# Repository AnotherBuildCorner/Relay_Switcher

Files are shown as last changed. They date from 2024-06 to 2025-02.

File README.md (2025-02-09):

# Relay_Switcher
DIY Relay bypass switcher for audio applications

Are you a Guitarist/Bassist?  Do you have a pedalboard that just keeps on getting more complicated?

Worried about losing the high end to the long capactive runs and buffers?

Or maybe you want the ability to control your Star-Trek level board from a small controller on your desk?

Or maybe you looked at the avaliable products, and practically fell out of your chair with the price tag?

Then look no further! In this project you'll find a modular capable, mono or stereo loop bypass switcher with wireless control capability.

## Notes:
V3 Jackless Is up and running in the same 6 back stacked form factor as V2. At this point I believe this represents the final version for this current system based on the WROOM32E. Why?
- After designing this board, I became aware of smaller form factor ESP32's such as the XIAO C6 platform, which is roughly the size of a US Quarter, and has enough GPIO pins to support at least 6 relays.
- These smaller implementations also appear to handle the mesh network past 4 nodes. In the past, while possible, implementing past 4 nodes required additional edits deep in the IDE that I was unable to implement at the time.
- With these smaller nodes, I may be able to use one C6 to control a 6 to 8 loop package box. Incorporated directly into the loop box. Meaning the only wires needed will be Power, and audio. No more RJ45 signal control wire.
- Further, with the practical limitiations of how many nodes are available lifted. The use of C6 nodes means the modularity is further improved to the point of having a control box behind the amp for example, in an effects loop configuration, and one or two on the main pedalboard.  Or even separate pedalboards for different uses.  Or different layers of a rack. The possibilites are endless.
- With a couple small onboard changes, power may even be supplied by the onboard USB connector. Which on it's face doesn't seem that helpful in a 9V power dominated space. However, commercial 5V to 9V power adapters are readily available, which means an entire system could be run from USB power, and by extension, the widely available USB power packs on the market. Why Boost the voltage, just to regulate back to 5V when the supply can be run on pure 5V?

V2 Jackless is up and running in a 6 bay stacked model. In the process a handful of lessons were picked up.
- One, for the jackless model a V3 utilizing probably 3 loops on a single panel with built in signal traces, and possibly breakaway functionality is likely. Attempting to wire the board interconnects resulted in a bit of a mess, one I'm not entirely happy with.
- Two, The original implementations use a completely separate power/control and signal path, not even the grounds are linked. This appears to be an error, and a future revision may include a solderable ground linking pad. In testing this linkage reduced the noise to virtually 0
- Three, the breakout board, while universal has a quirk. When used with the current V2 coms board, Power and ground on the 8 pins are not next to one another. Careful: This may fry some boards.
- Four, some of the pins used on the ESP-32 were linked to serial output, so when those pins are active, the serial monitor and control are disabled. 
## PCB's
### Main Driver Board
### V3
The V3 Design implements some of the noted design problems from V2. Development has continued exclusively with the 3.5mm pitch model. As these are the parts I have on hand. and increasing the terminal block size appears to have little practical benefit.

 Instead of utilizing individual loop boards, there are now a pair of boards linked by a ribbon cable. As a set, these combined boards can support either 6 mono/stereo loops, or 5 mono/stero loops and a mono input selector depending on relay configuration.

 Input Board
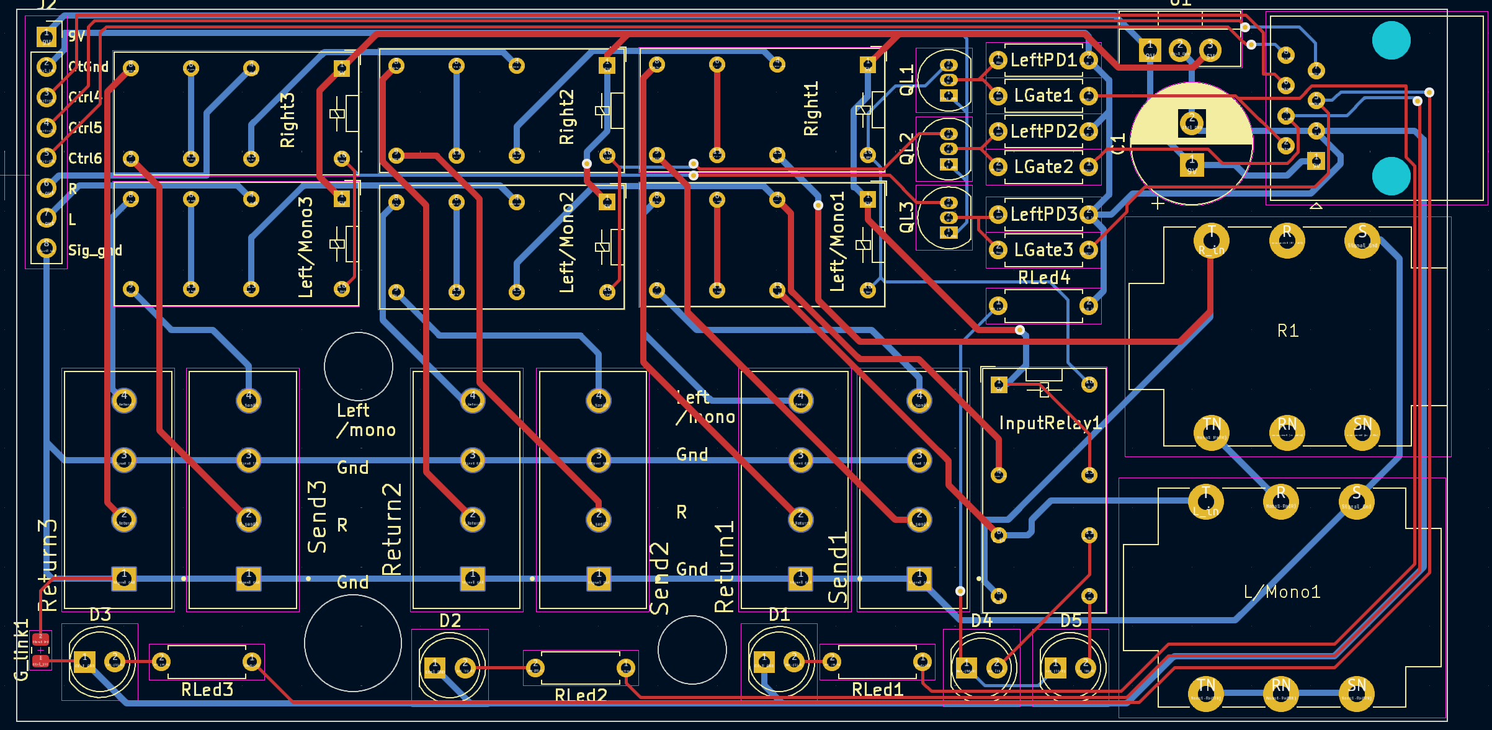
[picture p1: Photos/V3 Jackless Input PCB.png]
V3 jackless input PCB
 

 Output Board
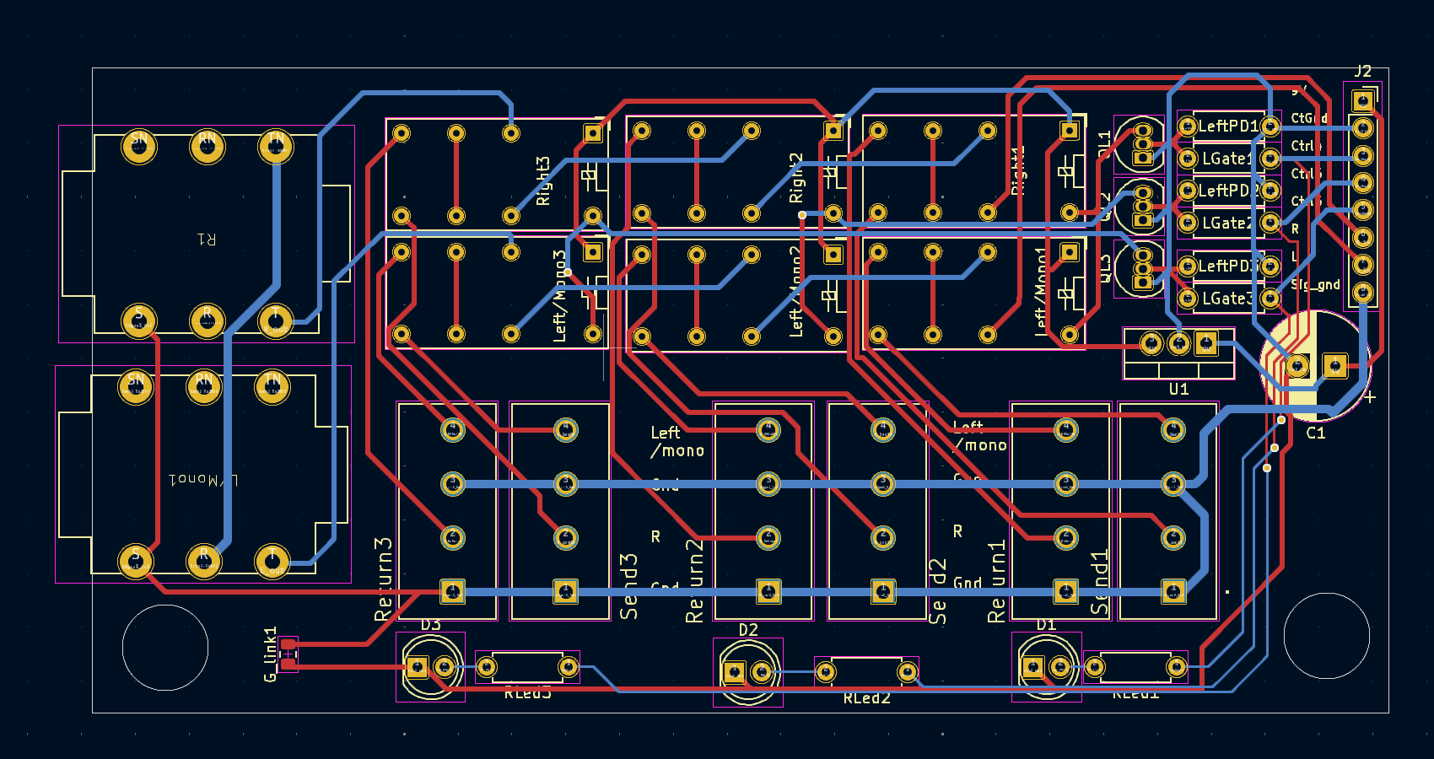
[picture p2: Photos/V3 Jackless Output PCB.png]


This change produces a couple of benefits. First is wiring is vastly improved. with the total wire soldering point count down from 7 per board ( L/R in, L/R out, Ground 9V, and Control signal.) Times 6 loop packages, for a total of 42 solder points. To 16 solder points total for the entire package. As well as being inline, ideal for a ribbon cable, as opposed to scattered across the board.

Additionally, the number of Voltage regulators is down from one per package, to one per PCB (with 3 loops on each). so a 66% reduction overall.

The mentioned power and signal ground linking has been added, provided by the G_link pads located on each PCB, in practice using booth may create a ground loop, so ideally soldering just one is reccomended.

Now the one loss from such a design (albeit minimal in practical usage) is the loops can no longer be order changed by moving around connectors inside the package (or perhaps in the future a complex multi relay network).  In practice this just means physically changing the order of the connected devices at the device instead, and is a minimal downside.

Both Boards Populated
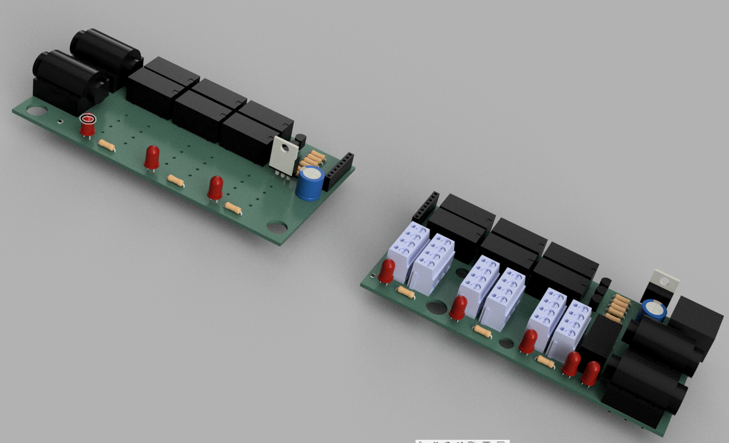
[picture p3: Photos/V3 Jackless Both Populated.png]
Populated


Complete Stacked model Assembly
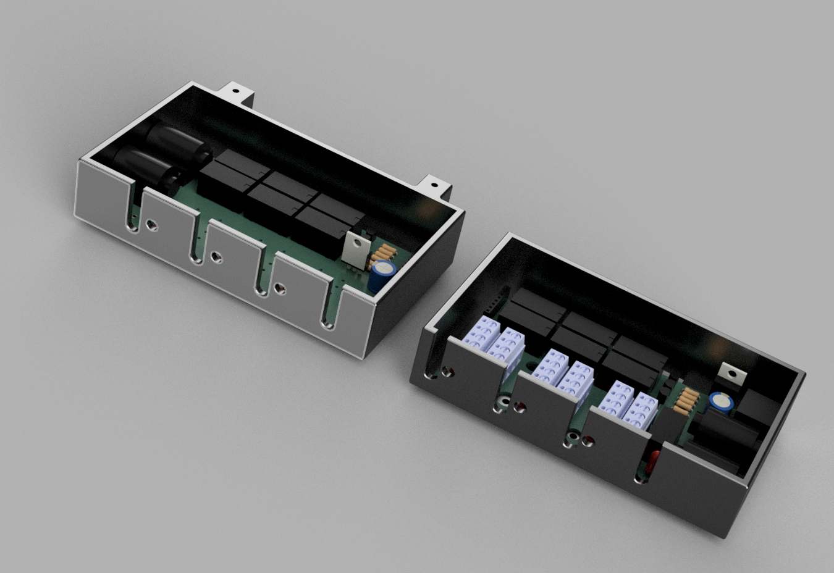
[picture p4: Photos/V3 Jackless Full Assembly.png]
Complete Assembly

### V2



V2 makes some significant improvements over the V1 design. And introduces a second design.
the changes are as follows
- Length of board reduced to 61mm Long
- Reduced count of 2n7000 MOSFET drivers from 3 to 1
- Tied status LED directly to the control output for a net -1 2n7000
- Tied the two relay coils together, controlled by single 2n7000

  Among the boards are now the standard stereo jack model, and a pair of new "jackless" models
  The jackless models utilize either a 4x3.5mm pitch or 4x5mm pitch screw terminal block on the IO. this reduces the cost per loop by up $10 in full implementation
  Additionally, it appears the space consumption overall will be significantly reduced with the new design
  




  The reduced board size should enable either the w/ jack or jackless versions to fit inside a standard 1032L Aluminium looper case
  In testing, the relay coils consume 30mA each, well under the 2n7000's maximum 200mA current.
  the new status LED position can also function as a pulldown for the inputs, reduces the 2n7000 count. And the originals had some current leakage which caused the led to be partially illuminated all the time

### V1


Pictured above is the main relay board. The core Arcitecture is one 5V coil DPDT Relay per signal channel. So for stereo configurations, two relays are required.
Each Relay is driven by a MOSFET 2n7000 switch circuit. As well as the status LED. All three MOSFET gates are tied to a common signal pin, and configured for 3.3V logic.

Each board is also equipped with a 74L05 5V regulator to drop the incoming 9V power, and provide supply for the relay switching.

Each board also has dual power connectors, as well as 3 pin 2.54mm spaced pins for the signal  this alows for easy connections between multiple boards in series.

Finally, the boards are set up to accept switched 1/4 inch stereo jacks. With the switches internally connected, so loops without connections pass signal in either active or inactive state.

(Add PCB wire photos here)

Of further note, was the consideration to keep audio, and control/ power wires as far away, and with minimal crossing as possible. This is to reduce crosstalk from the processor and power supplies into the audio path.

Future iterations will focus on compressing the PCB into a space suitable for a 16L Aluminium looper enclosure. Or possibly a design set up to directly connect to the mono/stereo signal wires, therby reducing the need for the 1/4 Barrel connectors, and reducing the required 1/4 Plugs by 1/2.  This also helps with space considerations.  Considering these plugs cost upwards of $4 each, cutting in half is most welcome, although this reduces how universal this device will be.

### Processor Board
### V2


Changes from V1 to V2 are a different footprint ESP32.  now the Wroom 32E is the standard, with 38 pins avaiable.
The individual pin headers have been replaced by 3x rj45 connectors. each is configured with 6 individual GPIO pins, as well as a 9V connection, and ground.
Additionally, a new breakout board for the rj45 on the receiver end has been created.


### V1


The microprocessor controlling the relays is an ESP32 Devkit C V3 Chosen for it's relative availability, low price, access to Arduino IDE code, and most importantly the dedicated ESP_NOW wireless communication protocol, which will be used to communicate between boards.
This is a relatively simple IO board for connecting to the GPIO of the processor board. The only extra element is another 74L05 voltage regulator connected to the 5V input of the dev board and the 4 pullup resistors slotted in on GPIO pins which only provide input (not suitable for the relay control, but there are already plenty of pins available for most applications).

One shortcoming, there may not be enough GPIO pins to handle the control switches, status LED's, screen, and rotary encoder(s). But this is all currently under development.

This version has a single easily remedied flaw. I had to create a footprint for the ESP32 used as they were what I had to hand, but appear to no longer be made. Well I flipped a ground and power connection, shorting 3.3V power to ground. For now it's just a matter of cutting the trace.

Future versions will probably switch to using a V4 devkit, or the newer devkits based on the S3 processor for more GPIO, and to retain more current availability. 

### IO Board
### V2


The new V2 board corrects an error in the input switching, resulting in one of the inputs being completely unusable.
Additionally, the board size has been significantly reduced in length. and the IO board direct pinouts have been moved directly under each jack.

### V1


This is very similar to the main relay boards.
The differences are the use of the single relay, the dual LED indicators, and the large electrolytic capacitor on the 9V rail.
The Capacitor is a filtering cap, as most of the 9V power supplies will be switched mode supplies, and noise prone.
The relay is no longer used to enable/disable a loop. but instead is used to switch between two possible inputs/outputs. With the other half of the relay dedicated to controlling the indicator LED's
lastly there are direct pinouts on the back of each 1/4 Barrel connector. Should switching features not be desired, these can be used to link the relay loops directly to an output without extra parts.

## Housings
### Control Housing 


### Relay housing V2 
JAckless model.


The latest relay switch is setup to accept 5 of the jackless relay boards, and one V2 IO board with the RJ45 connection board in front.  however this new model is half the height of V1, and is stackable. By splitting the units into modules of 5, this enables break points for things such as Volume pedals, and always on boosts between loop modules. Additional smaller size stackable modules will likely be produced in the future. No one single module can exceed more than 6 relay modules due to the RJ45 connection's configuration.

### Relay housing V1
(picure)
The current housing design uses horizontally stacked relay loops, with a total count of 10. Plus the input and output boards. The IO is located on the front for accesibility, with the loops located on the back.

### Control Housing
(picture
The current design is a single print, 6 switch control with provisions to add a 128X64 OLED.
At present this is in it's early stages, so no provisions to mount the control board, or a larger screen have been included. This will come around in V2  The footswitches are spaced to allow foot, or hand use currently. And the board can be purely powered from a 5V usb supply though the ESP32 board.

## Code
(Coming Soon...)

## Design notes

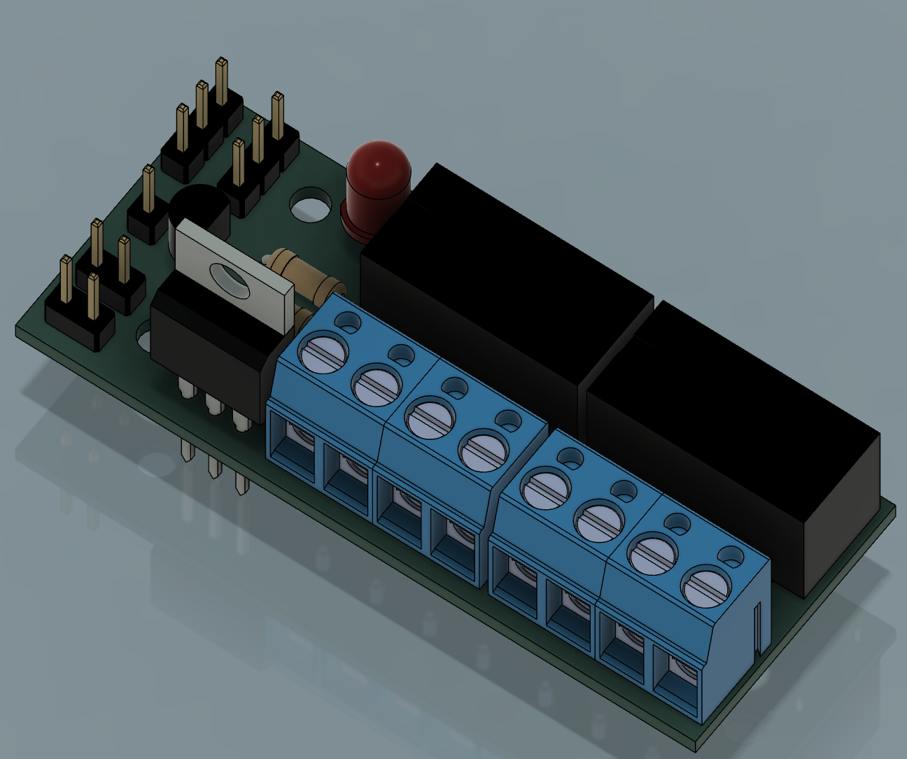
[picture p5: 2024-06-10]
Photos/Screenshot 2024-06-09 212600.png

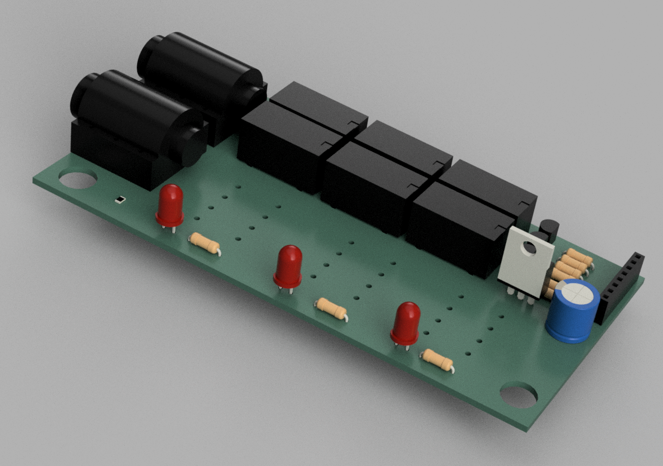
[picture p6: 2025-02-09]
Photos/V3 jackless Output only.png

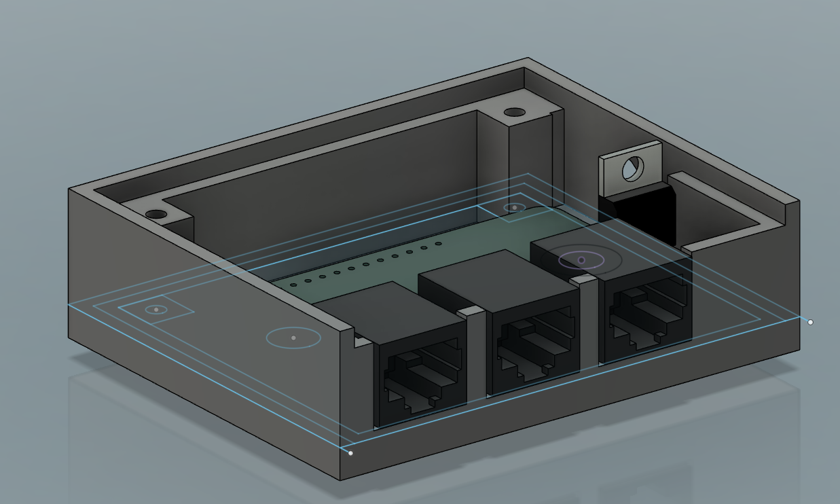
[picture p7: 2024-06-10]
Photos/Screenshot 2024-06-09 212513.png

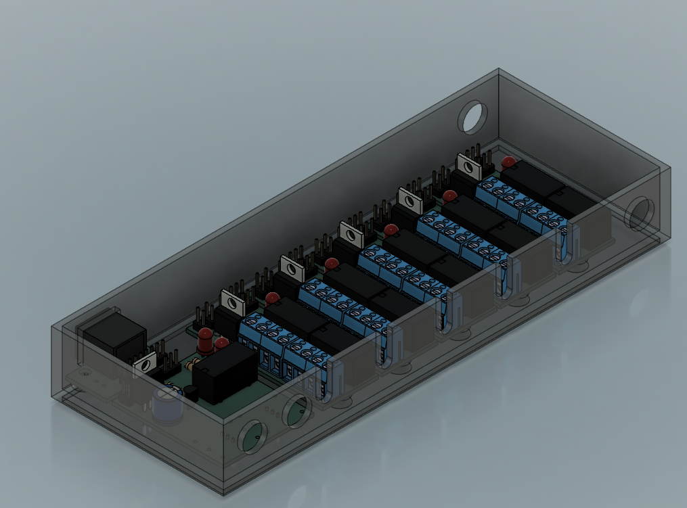
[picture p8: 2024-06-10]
Photos/Screenshot 2024-06-09 212331.png

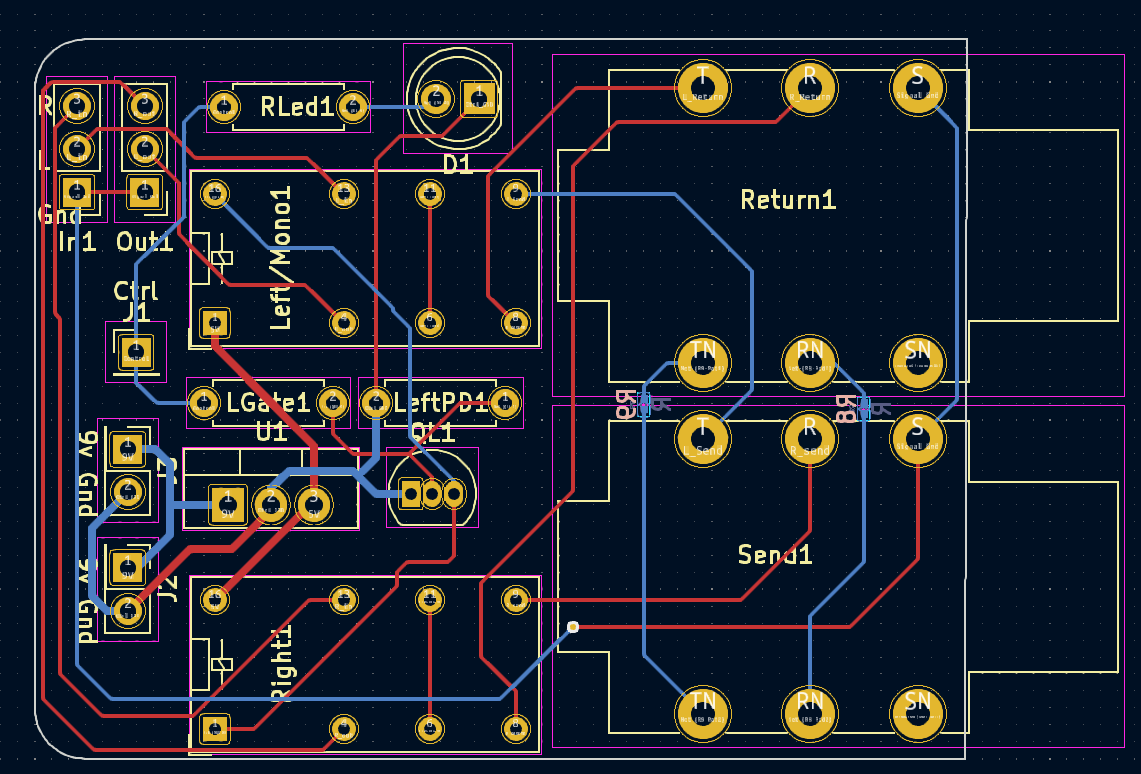
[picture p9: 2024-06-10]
Photos/Screenshot 2024-06-09 213055.png

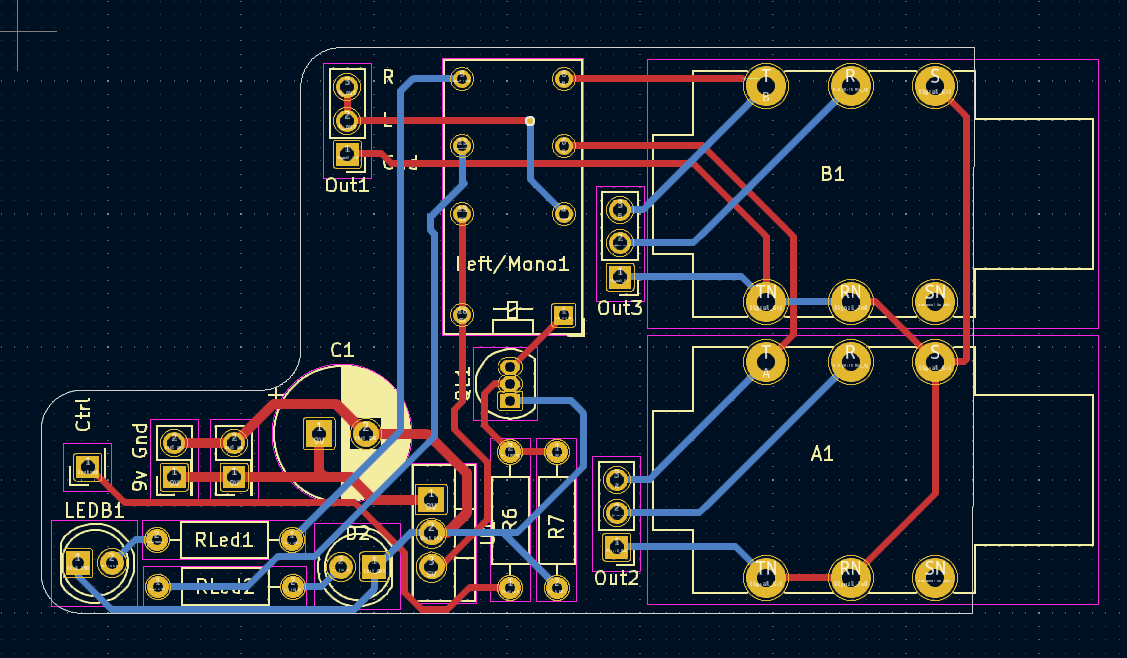
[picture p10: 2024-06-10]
Photos/Screenshot 2024-06-09 212951.png

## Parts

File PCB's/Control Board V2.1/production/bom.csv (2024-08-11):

Designator | Footprint | Quantity | Value | LCSC Part #
BYP1, BYP2, BYP3 | 0805 | 3 | ~
Extras1 | PinHeader_1x06_P2.54mm_Vertical | 1 | Conn_01x06_Pin
I2cScreen1 | PinHeader_1x04_P2.54mm_Vertical | 1 | Conn_01x05_Pin
J1 | TerminalBlock_Philmore_TB132_1x02_P5.00mm_Horizontal | 1 | Power In
J2 | PinHeader_1x03_P2.54mm_Vertical | 1 | LED Strip Conn
J3, J4 | RJ45_Amphenol_54602-x08_Horizontal | 2 | Expansion
LED1, LED2, LED3 | LED_Inolux_IN-PI554FCH_PLCC4_5.0x5.0mm_P3.2mm | 3 | IN-PI55TATPRPGPB
R1, R2, R_En_1 | R_Axial_DIN0207_L6.3mm_D2.5mm_P7.62mm_Horizontal | 3 | R
RPD1_1, RPD1_2, RPD1_3, RPD1_4, RPD1_5, RPD1_6, RPD1_7, RPD1_8, RPU1_10, RPU1_11, RPU1_9, RPU_Main_1 | 0805 | 12 | 10k
RotaryEnc1 | PinHeader_1x05_P2.54mm_Vertical | 1 | Conn_01x05_Pin
SW1, SW2, SW3, SW4, SW5, SW6, SW7, SW8 | TerminalBlock_4Ucon_1x02_P3.50mm_Vertical | 8 | SW_Push
U1 | MODULE_ESP32-DEVKITC-32E | 1 | ESP32-DEVKITC-32E
U2 | TO-220-3_Vertical | 1 | L7805
U3, U4, U5 | SOT-23-6 | 3 | TXS0101DBV
U6 | QSOP-16_3.9x4.9mm_P0.635mm | 1 | CD74HC4051M96

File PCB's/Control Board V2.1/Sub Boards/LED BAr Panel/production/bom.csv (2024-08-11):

Designator | Footprint | Quantity | Value | LCSC Part #
J1_5, J1_4, J1_3, J1_2, J1, J3_5, J3_4, J3_3, J3_2, J3 | PinHeader_1x03_P2.54mm_Vertical | 10 | LED Strip Conn
J2_5, J2_4, J2_3, J2_2, J2, J4_5, J4_4, J4_3, J4_2, J4 | PinHeader_1x03_P2.54mm_Vertical | 10 | Conn_01x03_Socket
KiKit_MB_10_1, KiKit_MB_10_2, KiKit_MB_10_3, KiKit_MB_10_4, KiKit_MB_11_1, KiKit_MB_11_2, KiKit_MB_11_3, KiKit_MB_11_4, KiKit_MB_12_1, KiKit_MB_12_2, KiKit_MB_12_3, KiKit_MB_12_4, KiKit_MB_13_1, KiKit_MB_13_2, KiKit_MB_13_3, KiKit_MB_13_4, KiKit_MB_14_1, KiKit_MB_14_2, KiKit_MB_14_3, KiKit_MB_14_4, KiKit_MB_15_1, KiKit_MB_15_2, KiKit_MB_15_3, KiKit_MB_15_4, KiKit_MB_16_1, KiKit_MB_16_2, KiKit_MB_16_3, KiKit_MB_16_4, KiKit_MB_17_1, KiKit_MB_17_2, KiKit_MB_17_3, KiKit_MB_17_4, KiKit_MB_18_1, KiKit_MB_18_2, KiKit_MB_18_3, KiKit_MB_18_4, KiKit_MB_19_1, KiKit_MB_19_2, KiKit_MB_19_3, KiKit_MB_19_4, KiKit_MB_1_1, KiKit_MB_1_2, KiKit_MB_1_3, KiKit_MB_1_4, KiKit_MB_20_1, KiKit_MB_20_2, KiKit_MB_20_3, KiKit_MB_20_4, KiKit_MB_21_1, KiKit_MB_21_2, KiKit_MB_21_3, KiKit_MB_21_4, KiKit_MB_22_1, KiKit_MB_22_2, KiKit_MB_22_3, KiKit_MB_22_4, KiKit_MB_23_1, KiKit_MB_23_2, KiKit_MB_23_3, KiKit_MB_23_4, KiKit_MB_24_1, KiKit_MB_24_2, KiKit_MB_24_3, KiKit_MB_24_4, KiKit_MB_25_1, KiKit_MB_25_2, KiKit_MB_25_3, KiKit_MB_25_4, KiKit_MB_26_1, KiKit_MB_26_2, KiKit_MB_26_3, KiKit_MB_26_4, KiKit_MB_27_1, KiKit_MB_27_2, KiKit_MB_27_3, KiKit_MB_27_4, KiKit_MB_28_1, KiKit_MB_28_2, KiKit_MB_28_3, KiKit_MB_28_4, KiKit_MB_29_1, KiKit_MB_29_2, KiKit_MB_29_3, KiKit_MB_29_4, KiKit_MB_2_1, KiKit_MB_2_2, KiKit_MB_2_3, KiKit_MB_2_4, KiKit_MB_30_1, KiKit_MB_30_2, KiKit_MB_30_3, KiKit_MB_30_4, KiKit_MB_31_1, KiKit_MB_31_2, KiKit_MB_31_3, KiKit_MB_31_4, KiKit_MB_32_1, KiKit_MB_32_2, KiKit_MB_32_3, KiKit_MB_32_4, KiKit_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 | NPTH | 192 | NPTH
LED1_5, LED1_4, LED1_3, LED1_2, LED1, LED2_5, LED2_4, LED2_3, LED2_2, LED2 | LED_IN-PI55TAT_INL | 10 | IN-PI55TATPRPGPB

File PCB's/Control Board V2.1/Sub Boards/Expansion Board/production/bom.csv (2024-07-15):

Designator | Footprint | Quantity | Value | LCSC Part #
J2 | PinHeader_1x03_P2.54mm_Vertical | 1 | LED Strip Conn
J3 | RJ45_Amphenol_54602-x08_Horizontal | 1 | Expansion
RPD1_1, RPD1_2, RPD1_3, RPD1_4, RPD1_5, RPD1_6, RPD1_7, RPD1_8 | 0805 | 8 | 10k
SW1, SW3, SW4, SW5, SW6, SW7, SW8 | TerminalBlock_4Ucon_1x02_P3.50mm_Vertical | 7 | SW_Push
SW2 | TerminalBlock_4Ucon_1x02_P3.50mm_Vertical | 1 | ~
U6 | QSOP-16_3.9x4.9mm_P0.635mm | 1 | CD74HC4051M96

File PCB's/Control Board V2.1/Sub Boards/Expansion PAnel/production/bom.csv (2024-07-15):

Designator | Footprint | Quantity | Value | LCSC Part #
J2_2, J2 | PinHeader_1x03_P2.54mm_Vertical | 2 | LED Strip Conn
J3_2, J3 | RJ45_Amphenol_54602-x08_Horizontal | 2 | Expansion
KiKit_MB_1_1, KiKit_MB_1_2, KiKit_MB_1_3, KiKit_MB_1_4, KiKit_MB_2_1, KiKit_MB_2_2, KiKit_MB_2_3, KiKit_MB_2_4, KiKit_MB_3_1, KiKit_MB_3_2, KiKit_MB_3_3, KiKit_MB_3_4, KiKit_MB_4_1, KiKit_MB_4_2, KiKit_MB_4_3, KiKit_MB_4_4, KiKit_MB_5_1, KiKit_MB_5_2, KiKit_MB_5_3, KiKit_MB_5_4, KiKit_MB_6_1, KiKit_MB_6_2, KiKit_MB_6_3, KiKit_MB_6_4 | NPTH | 24 | NPTH
RPD1_1_2, RPD1_1, RPD1_2_2, RPD1_2, RPD1_3_2, RPD1_3, RPD1_4_2, RPD1_4, RPD1_5_2, RPD1_5, RPD1_6_2, RPD1_6, RPD1_7_2, RPD1_7, RPD1_8_2, RPD1_8 | 0805 | 16 | 10k
SW1_2, SW1, SW3_2, SW3, SW4_2, SW4, SW5_2, SW5, SW6_2, SW6, SW7_2, SW7, SW8_2, SW8 | TerminalBlock_4Ucon_1x02_P3.50mm_Vertical | 14 | SW_Push
SW2_2, SW2 | TerminalBlock_4Ucon_1x02_P3.50mm_Vertical | 2 | ~
U6_2, U6 | QSOP-16_3.9x4.9mm_P0.635mm | 2 | CD74HC4051M96

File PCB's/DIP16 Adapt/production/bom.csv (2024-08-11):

Designator | Footprint | Quantity | Value | LCSC Part #
KiKit_MB_10_1, KiKit_MB_10_2, KiKit_MB_10_3, KiKit_MB_10_4, KiKit_MB_11_1, KiKit_MB_11_2, KiKit_MB_11_3, KiKit_MB_11_4, KiKit_MB_12_1, KiKit_MB_12_2, KiKit_MB_12_3, KiKit_MB_12_4, KiKit_MB_13_1, KiKit_MB_13_2, KiKit_MB_13_3, KiKit_MB_13_4, KiKit_MB_14_1, KiKit_MB_14_2, KiKit_MB_14_3, KiKit_MB_14_4, KiKit_MB_15_1, KiKit_MB_15_2, KiKit_MB_15_3, KiKit_MB_15_4, KiKit_MB_16_1, KiKit_MB_16_2, KiKit_MB_16_3, KiKit_MB_16_4, KiKit_MB_17_1, KiKit_MB_17_2, KiKit_MB_17_3, KiKit_MB_17_4, KiKit_MB_18_1, KiKit_MB_18_2, KiKit_MB_18_3, KiKit_MB_18_4, KiKit_MB_19_1, KiKit_MB_19_2, KiKit_MB_19_3, KiKit_MB_19_4, KiKit_MB_1_1, KiKit_MB_1_2, KiKit_MB_1_3, KiKit_MB_1_4, KiKit_MB_20_1, KiKit_MB_20_2, KiKit_MB_20_3, KiKit_MB_20_4, KiKit_MB_21_1, KiKit_MB_21_2, KiKit_MB_21_3, KiKit_MB_21_4, KiKit_MB_22_1, KiKit_MB_22_2, KiKit_MB_22_3, KiKit_MB_22_4, KiKit_MB_23_1, KiKit_MB_23_2, KiKit_MB_23_3, KiKit_MB_23_4, KiKit_MB_24_1, KiKit_MB_24_2, KiKit_MB_24_3, KiKit_MB_24_4, KiKit_MB_25_1, KiKit_MB_25_2, KiKit_MB_25_3, KiKit_MB_25_4, KiKit_MB_26_1, KiKit_MB_26_2, KiKit_MB_26_3, KiKit_MB_26_4, KiKit_MB_27_1, KiKit_MB_27_2, KiKit_MB_27_3, KiKit_MB_27_4, KiKit_MB_28_1, KiKit_MB_28_2, KiKit_MB_28_3, KiKit_MB_28_4, KiKit_MB_29_1, KiKit_MB_29_2, KiKit_MB_29_3, KiKit_MB_29_4, KiKit_MB_2_1, KiKit_MB_2_2, KiKit_MB_2_3, KiKit_MB_2_4, KiKit_MB_30_1, KiKit_MB_30_2, KiKit_MB_30_3, KiKit_MB_30_4, KiKit_MB_31_1, KiKit_MB_31_2, KiKit_MB_31_3, KiKit_MB_31_4, KiKit_MB_32_1, KiKit_MB_32_2, KiKit_MB_32_3, KiKit_MB_32_4, KiKit_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 | NPTH | 192 | NPTH
U1_16, U1_15, U1_14, U1_13, U1_12, U1_11, U1_10, U1_9, U1_8, U1_7, U1_6, U1_5, U1_4, U1_3, U1_2, U1 | DIP-16_W7.62mm_LongPads | 16 | CD74HC4051M96
U2_16, U2_15, U2_14, U2_13, U2_12, U2_11, U2_10, U2_9, U2_8, U2_7, U2_6, U2_5, U2_4, U2_3, U2_2, U2 | D16 | 16 | CD74HC4051M96
U3_16, U3_15, U3_14, U3_13, U3_12, U3_11, U3_10, U3_9, U3_8, U3_7, U3_6, U3_5, U3_4, U3_3, U3_2, U3 | PW16 | 16 | CD74HC4051M96

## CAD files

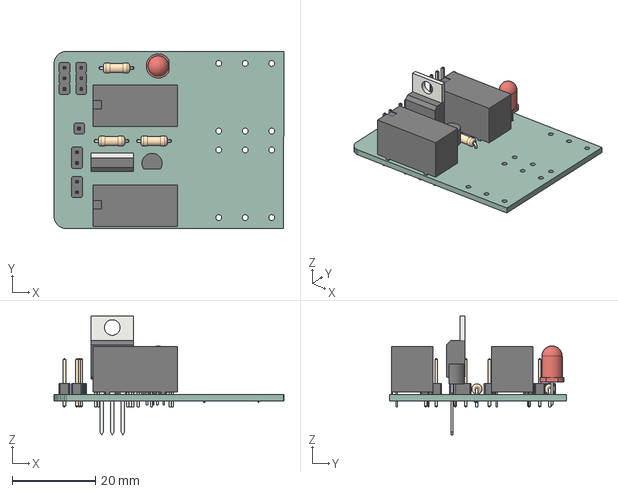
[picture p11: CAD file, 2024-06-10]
PCB's/Loop Board V2/PedalboardMain.step
55.1 x 42.5 x 28.5 mm
PedalboardMain PCB

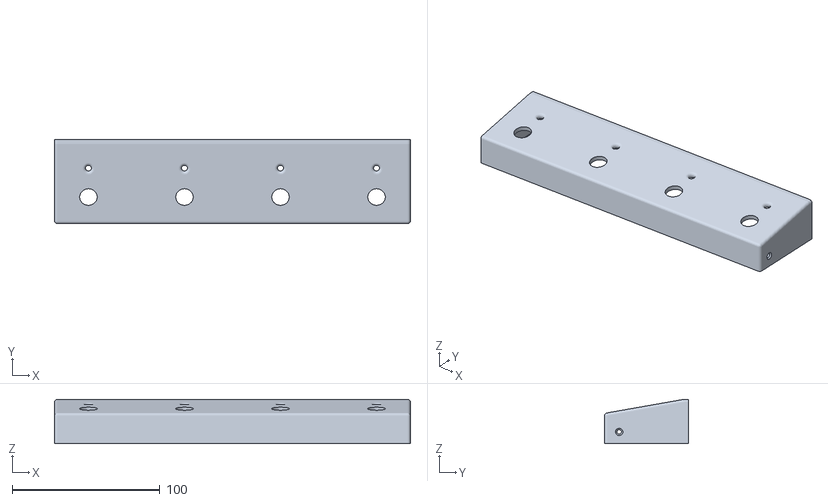
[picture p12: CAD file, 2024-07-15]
3D Print Models/8 Switch Footswitch/8 bay front.stl
241.0 x 57.0 x 30.1

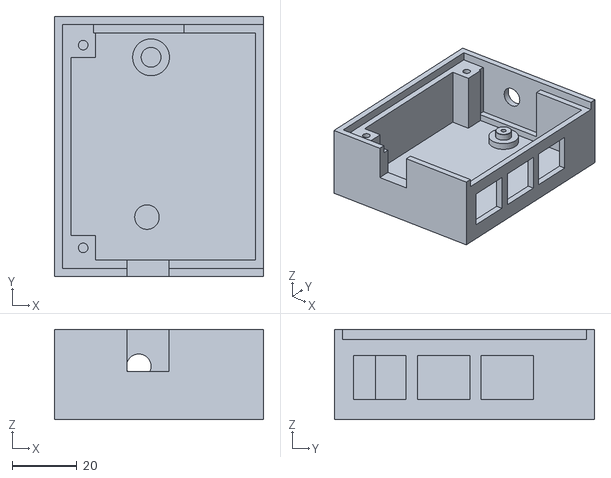
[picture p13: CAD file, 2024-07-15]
3D Print Models/V2 Receiver Box/Control Box.stl
64.8 x 80.6 x 27.9

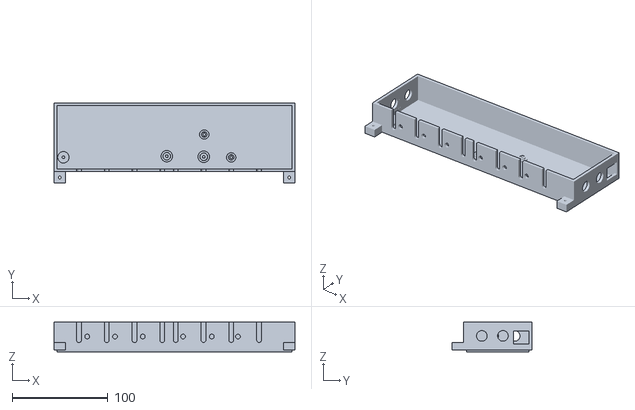
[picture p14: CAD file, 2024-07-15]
3D Print Models/V3 Jackless/6 Bay Long models/Top-Mid.stl
251.5 x 84.0 x 31.0

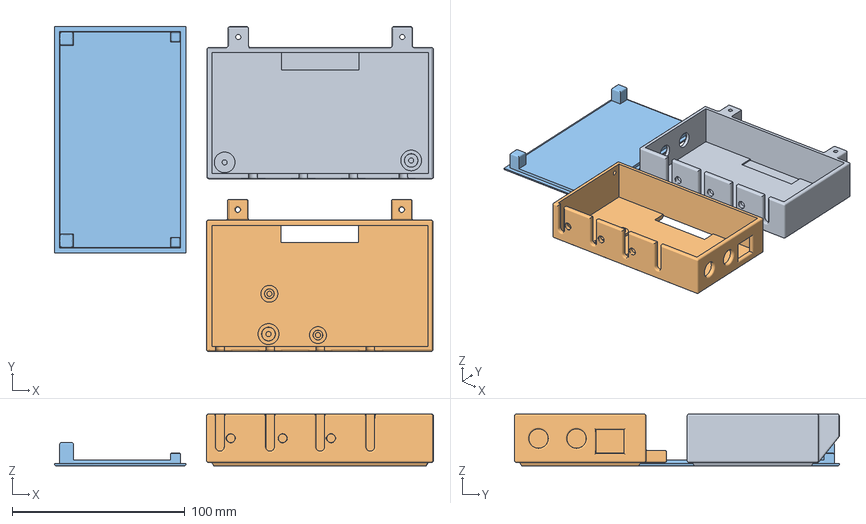
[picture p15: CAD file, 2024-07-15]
3D Print Models/V3 Jackless/6 Bay Stack models/6 bay stack V3 board v1.3mf
219.3 x 188.0 x 30.0 mm
Bottom-output.stl
Top-input.stl
Lid.stl

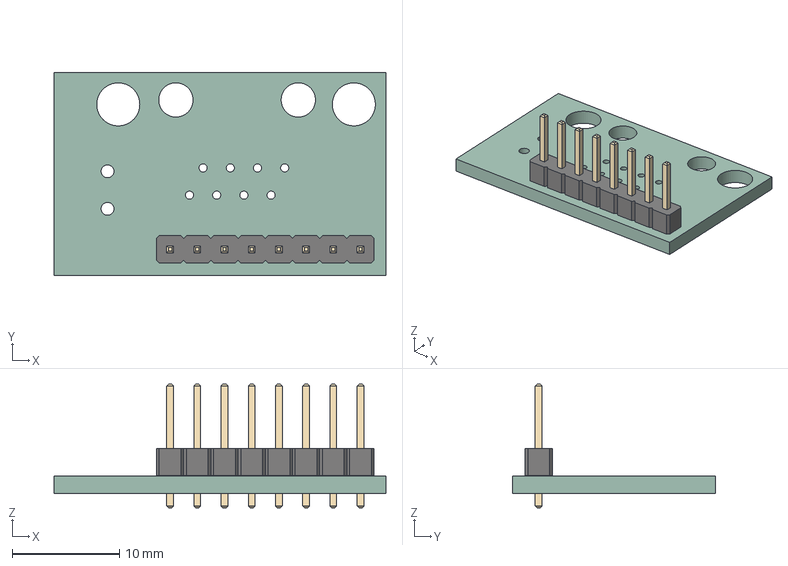
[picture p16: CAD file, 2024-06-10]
PCB's/8P breakout header/8P breakout header.step
31.0 x 19.0 x 11.5 mm
8P breakout header PCB

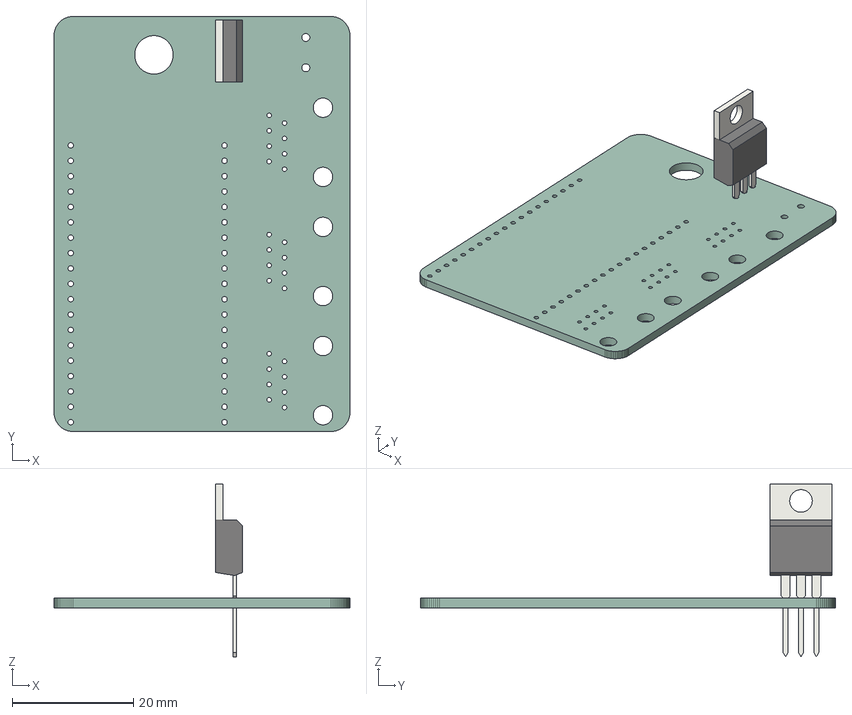
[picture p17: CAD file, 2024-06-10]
PCB's/Coms Board V2/Coms Board V2.step
48.9 x 68.6 x 28.5 mm
Coms Board V2 PCB

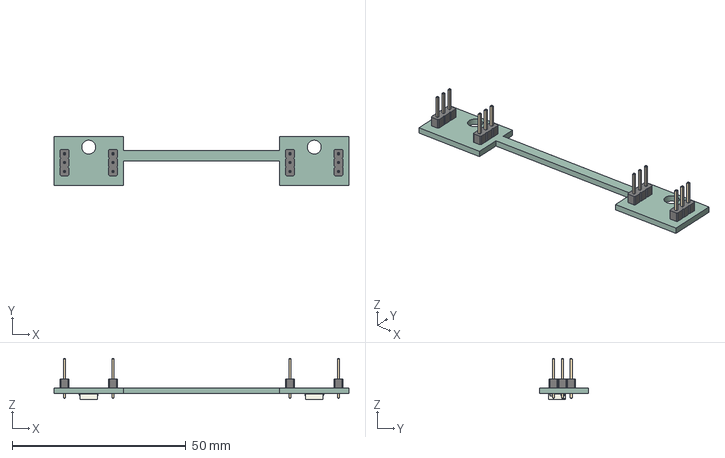
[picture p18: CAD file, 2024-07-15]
PCB's/Control Board V2.1/Sub Boards/LED bar/LED bar.step
85.0 x 14.0 x 11.9 mm
LED bar PCB

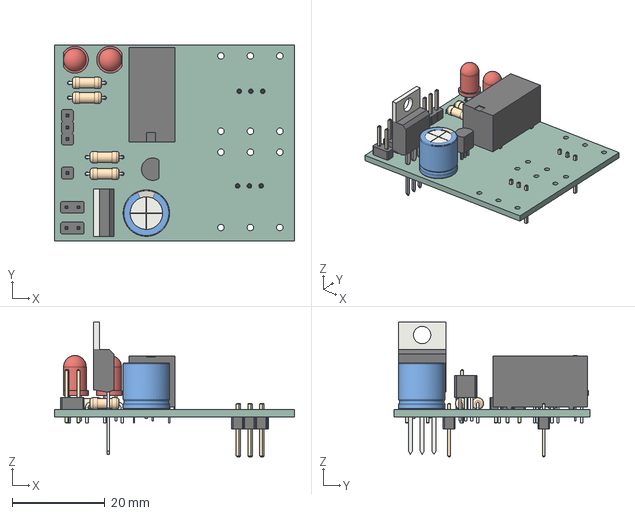
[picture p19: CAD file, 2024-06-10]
PCB's/In_out V2/IO.step
51.7 x 42.3 x 29.0 mm
IO PCB

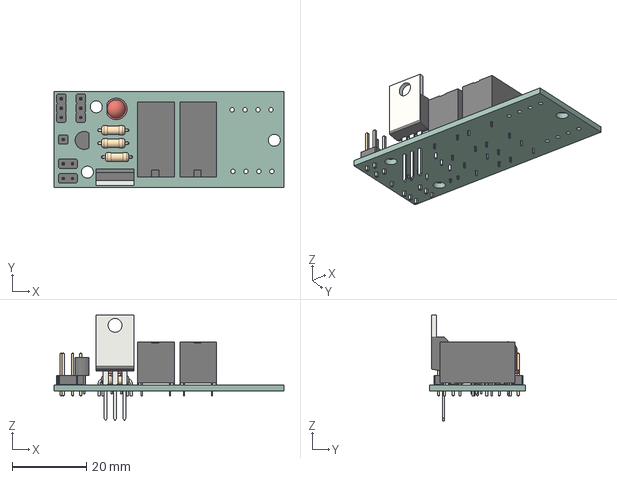
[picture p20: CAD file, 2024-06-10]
PCB's/Loop Board V3 Jackless/Loop Board 3 Jackless Input/JacklessLoop.step
62.0 x 26.0 x 28.5 mm
PedalboardMain PCB

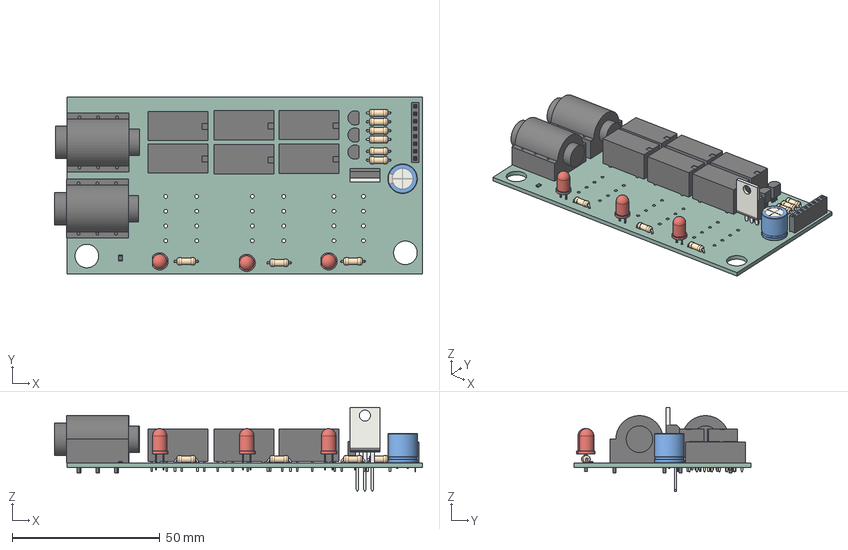
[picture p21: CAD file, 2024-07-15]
PCB's/Loop Board V3 Jackless/Loop Board 3 Jackless Output/Loop Board 3 Jackless Output.step
124.7 x 60.0 x 28.5 mm
Loop Board 3 Jackless Output PCB

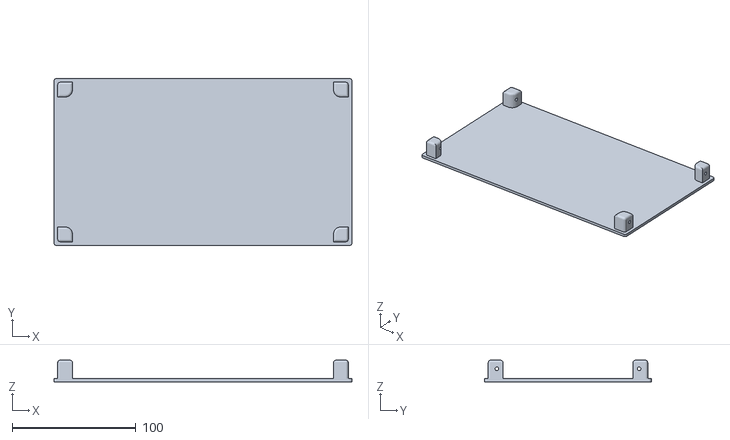
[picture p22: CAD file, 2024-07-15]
3D Print Models/8 Switch Footswitch/8 bay bottom.stl
241.0 x 135.0 x 17.5

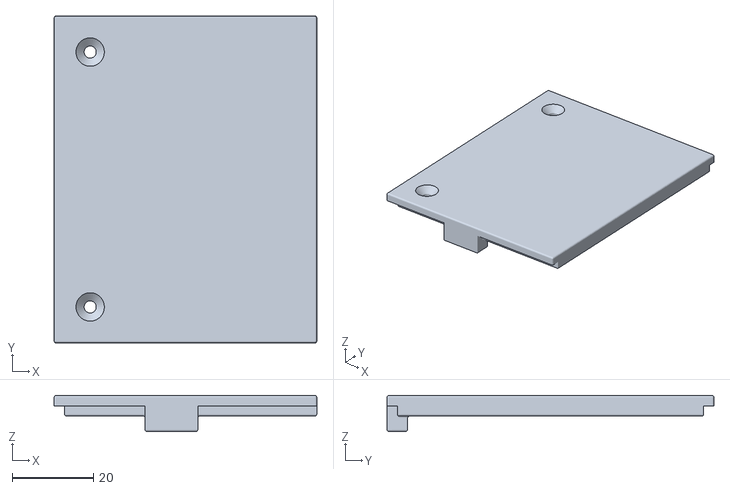
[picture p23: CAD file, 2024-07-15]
3D Print Models/V2 Receiver Box/Control Lid.stl
64.8 x 80.6 x 8.89

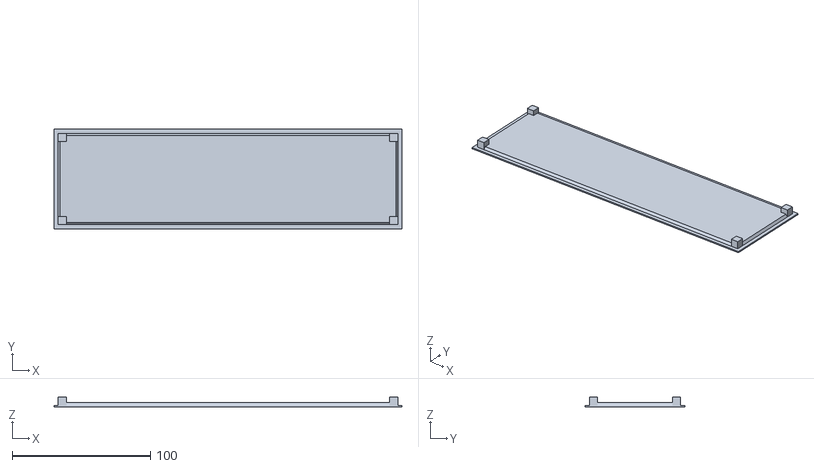
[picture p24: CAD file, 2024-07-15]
3D Print Models/V3 Jackless/6 Bay Long models/lg_lid.stl
251.5 x 72.0 x 7.00

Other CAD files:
3D Print Models/V3 Jackless/6 Bay Stack models/Top-input.stl
PCB's/Loop Board V3 Jackless/Loop Board 3 Jackless Input/Loop Board 3 Jackless Input.step
3D Print Models/8 Switch Footswitch/8 bay back.stl
3D Print Models/V2 Jackless/Long/5 Bay Lid.stl
3D Print Models/V2 Jackless/Long/5 Bay switch.3mf
3D Print Models/V2 Jackless/Long/5 Bay switch.stl
3D Print Models/V2 Jackless/Stacked/Base.3mf
3D Print Models/V2 Jackless/Stacked/Bottom Box.stl
3D Print Models/V2 Jackless/Stacked/Small Lid.stl
3D Print Models/V2 Jackless/Stacked/Small Stack Lid.stl
3D Print Models/V2 Jackless/Stacked/Top Box no IO.stl
3D Print Models/V2 Jackless/Stacked/Top Box.stl
3D Print Models/V3 Jackless/6 Bay Long models/Base.stl
3D Print Models/V3 Jackless/6 Bay Long models/Top_input.stl
3D Print Models/V3 Jackless/6 Bay Stack models/Bottom-output.stl
3D Print Models/V3 Jackless/6 Bay Stack models/Lid.stl

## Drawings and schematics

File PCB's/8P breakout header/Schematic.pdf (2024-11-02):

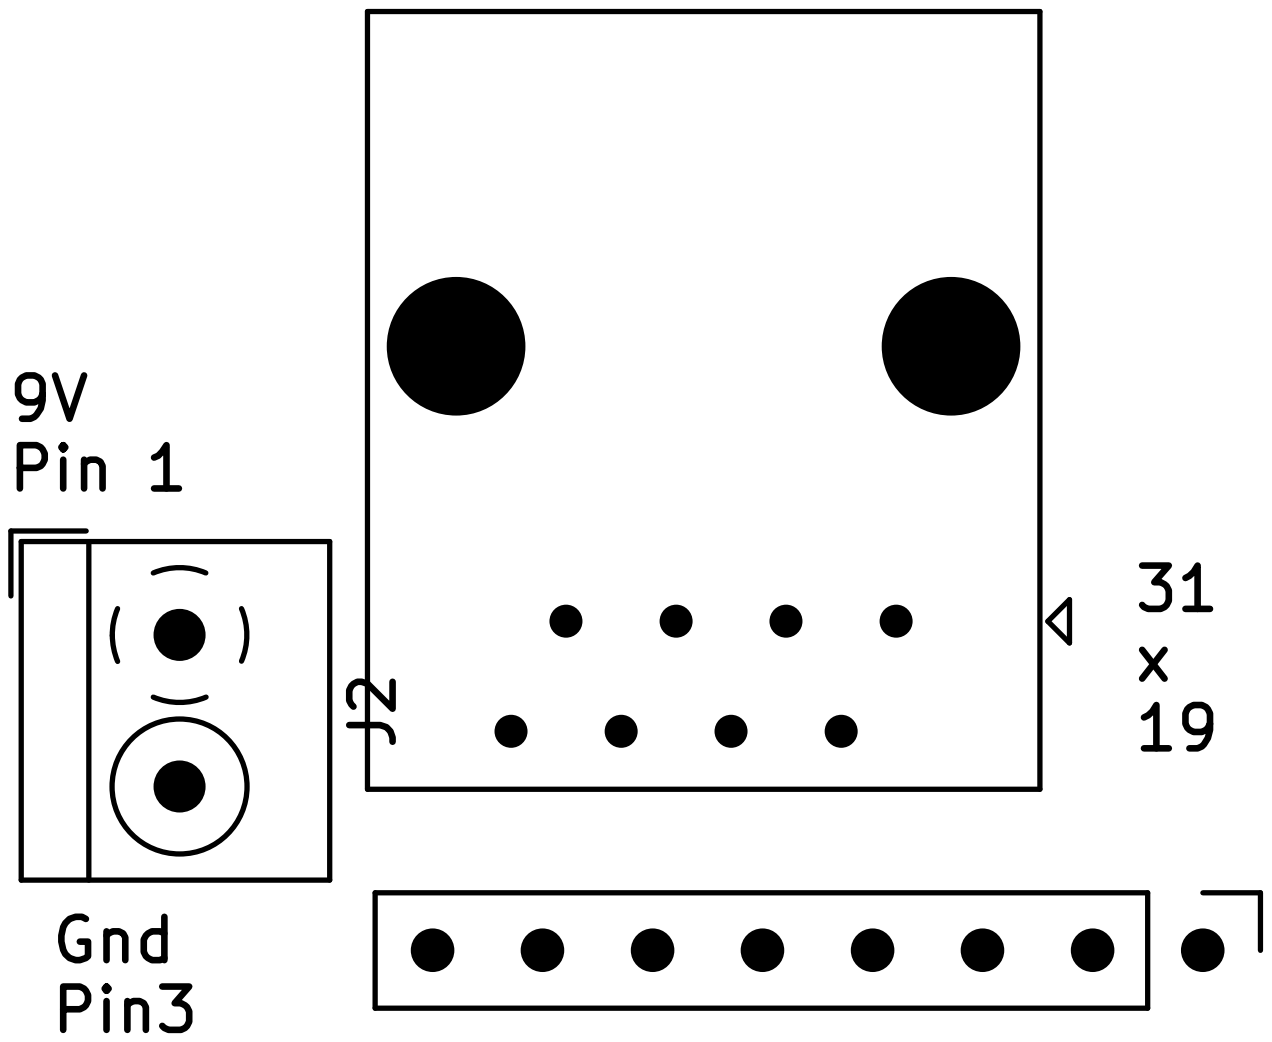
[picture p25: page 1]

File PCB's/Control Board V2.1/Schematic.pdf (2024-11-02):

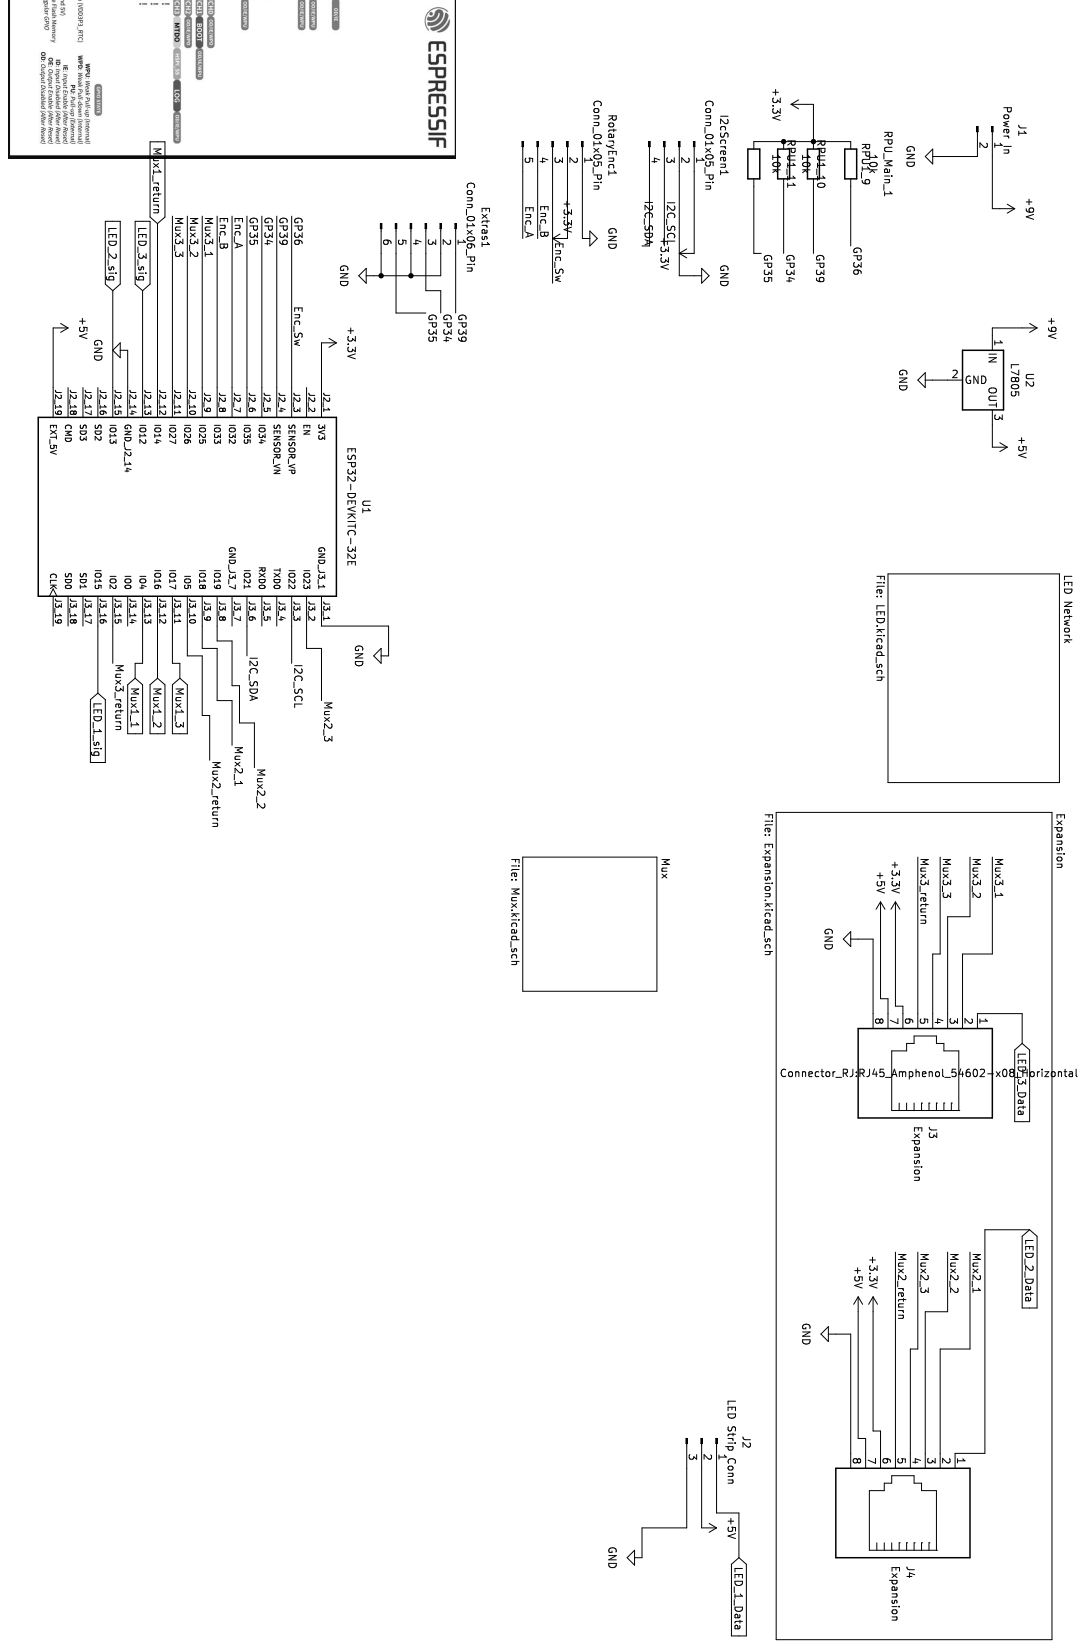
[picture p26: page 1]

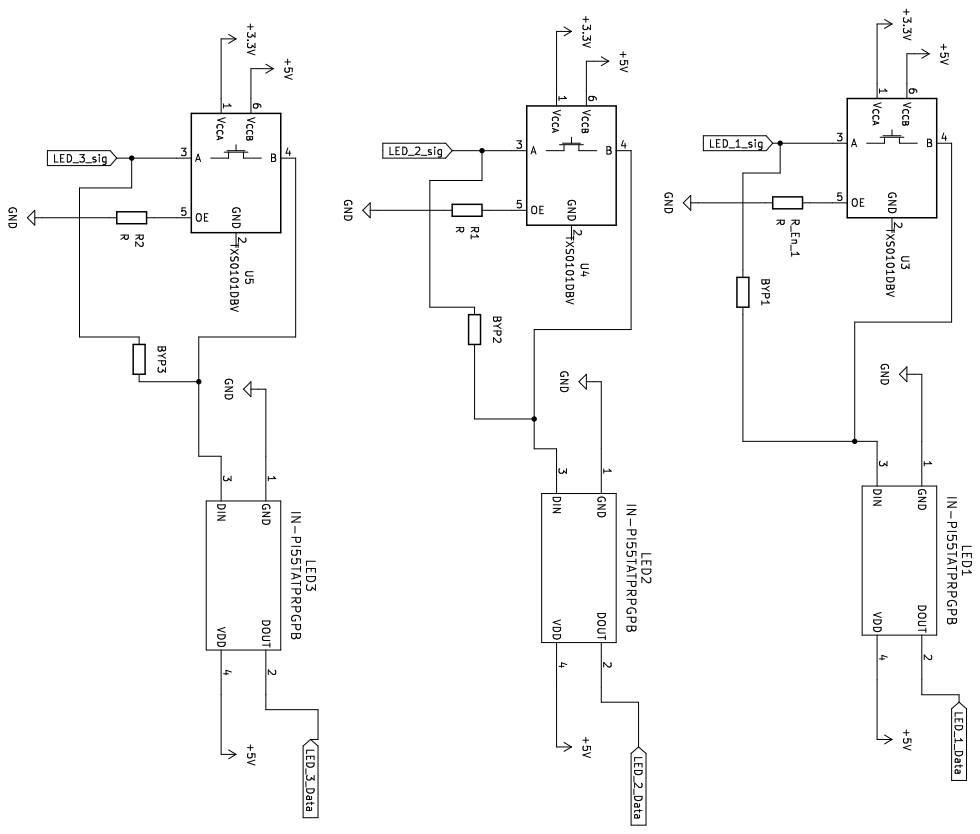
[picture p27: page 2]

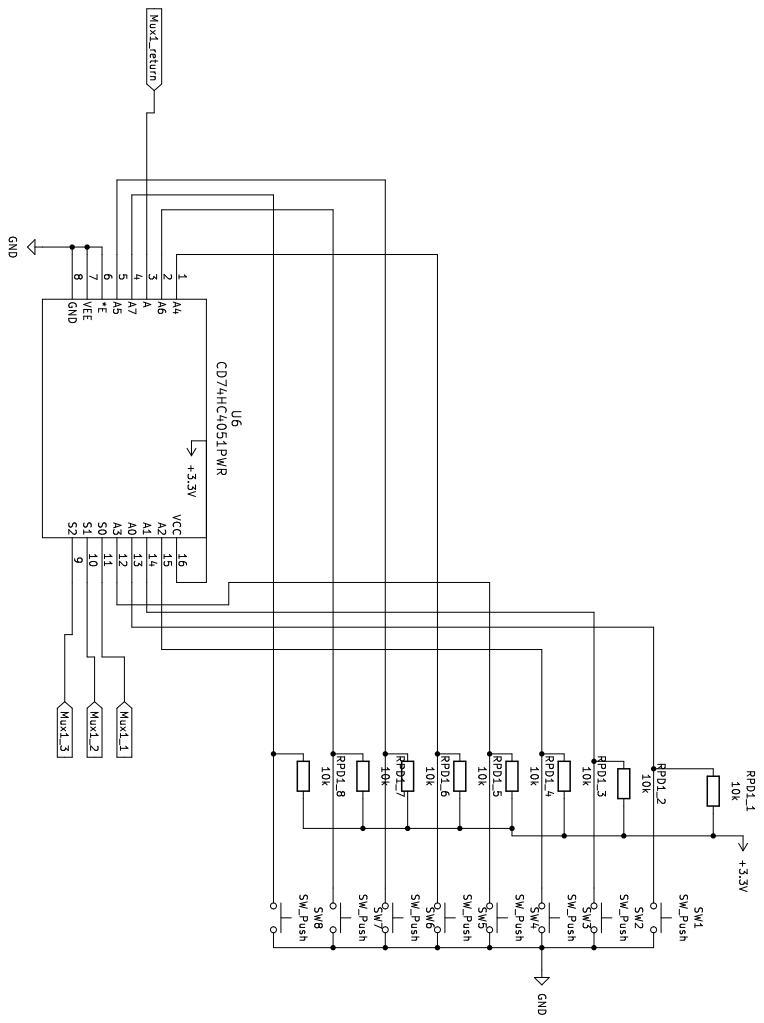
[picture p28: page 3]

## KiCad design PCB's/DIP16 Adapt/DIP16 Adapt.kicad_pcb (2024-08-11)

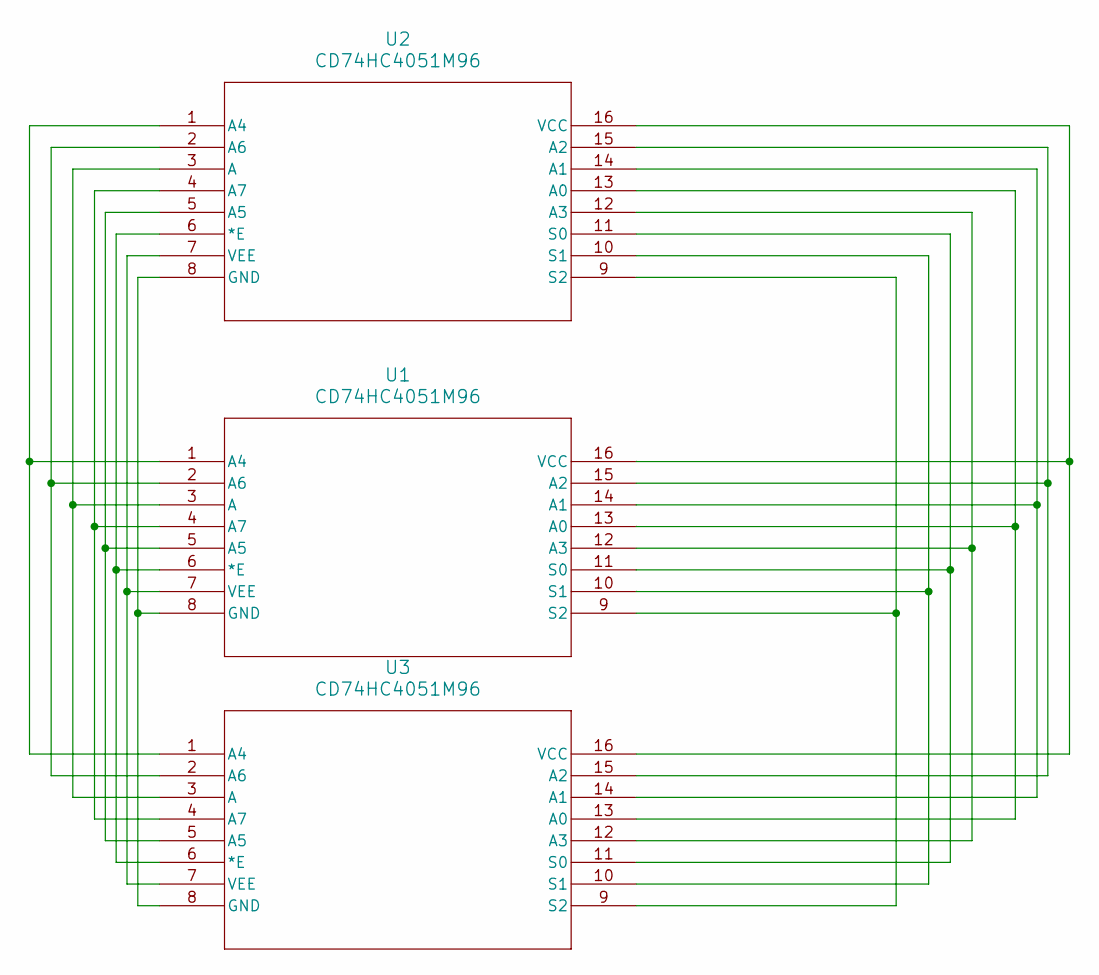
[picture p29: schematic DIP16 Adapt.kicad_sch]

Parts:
U1: CD74HC4051M96; DIP-16_W7.62mm_LongPads
U2: CD74HC4051M96; D16
U3: CD74HC4051M96; PW16

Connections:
unnamed: U1.6 (*E), U2.6 (*E), U3.6 (*E)
unnamed: U1.13 (A0), U2.13 (A0), U3.13 (A0)
unnamed: U1.14 (A1), U2.14 (A1), U3.14 (A1)
unnamed: U1.15 (A2), U2.15 (A2), U3.15 (A2)
unnamed: U1.12 (A3), U2.12 (A3), U3.12 (A3)
unnamed: U1.1 (A4), U2.1 (A4), U3.1 (A4)
unnamed: U1.5 (A5), U2.5 (A5), U3.5 (A5)
unnamed: U1.2 (A6), U2.2 (A6), U3.2 (A6)
unnamed: U1.4 (A7), U2.4 (A7), U3.4 (A7)
unnamed: U1.3 (A), U2.3 (A), U3.3 (A)
unnamed: U1.8 (GND), U2.8 (GND), U3.8 (GND)
unnamed: U1.11 (S0), U2.11 (S0), U3.11 (S0)
unnamed: U1.10 (S1), U2.10 (S1), U3.10 (S1)
unnamed: U1.9 (S2), U2.9 (S2), U3.9 (S2)
unnamed: U1.16 (VCC), U2.16 (VCC), U3.16 (VCC)
unnamed: U1.7 (VEE), U2.7 (VEE), U3.7 (VEE)

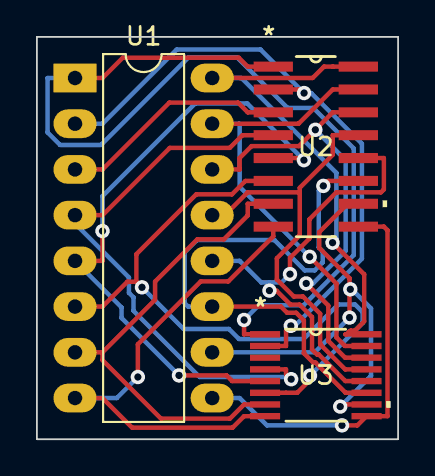
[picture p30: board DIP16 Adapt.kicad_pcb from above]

Board: 2 copper layers, 20.1 x 22.4 mm, 3 parts (0 on the bottom side), 16 nets.

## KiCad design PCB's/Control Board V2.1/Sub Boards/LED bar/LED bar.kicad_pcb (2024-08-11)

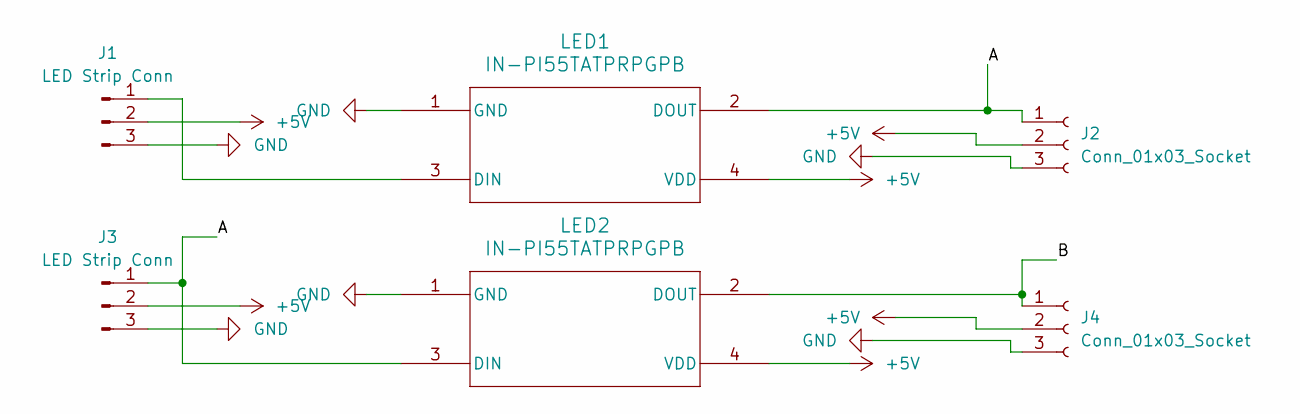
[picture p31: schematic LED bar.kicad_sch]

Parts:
J1, J3: LED Strip Conn; PinHeader_1x03_P2.54mm_Vertical
J2, J4: Conn_01x03_Socket; PinHeader_1x03_P2.54mm_Vertical
LED1, LED2: IN-PI55TATPRPGPB; LED_IN-PI55TAT_INL

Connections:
+5V: J1.2, J2.2, J3.2, J4.2, LED1.4 (VDD), LED2.4 (VDD)
/A: J2.1, J3.1, LED1.2 (DOUT), LED2.3 (DIN)
/B: J4.1, LED2.2 (DOUT)
GND: J1.3, J2.3, J3.3, J4.3, LED1.1 (GND), LED2.1 (GND)
unnamed: J1.1, LED1.3 (DIN)

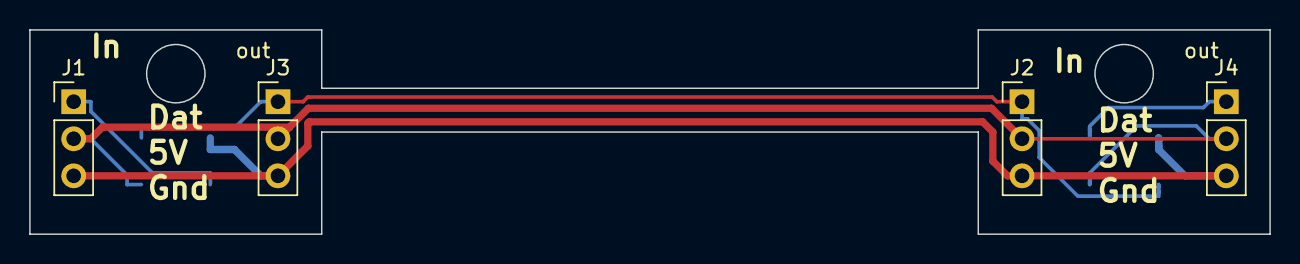
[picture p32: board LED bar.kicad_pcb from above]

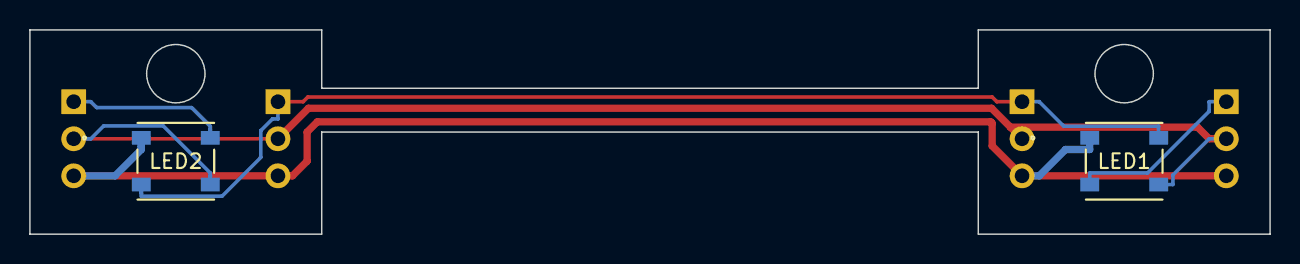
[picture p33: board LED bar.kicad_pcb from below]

Board: 2 copper layers, 85.0 x 14.0 mm, 6 parts (2 on the bottom side), 5 nets.

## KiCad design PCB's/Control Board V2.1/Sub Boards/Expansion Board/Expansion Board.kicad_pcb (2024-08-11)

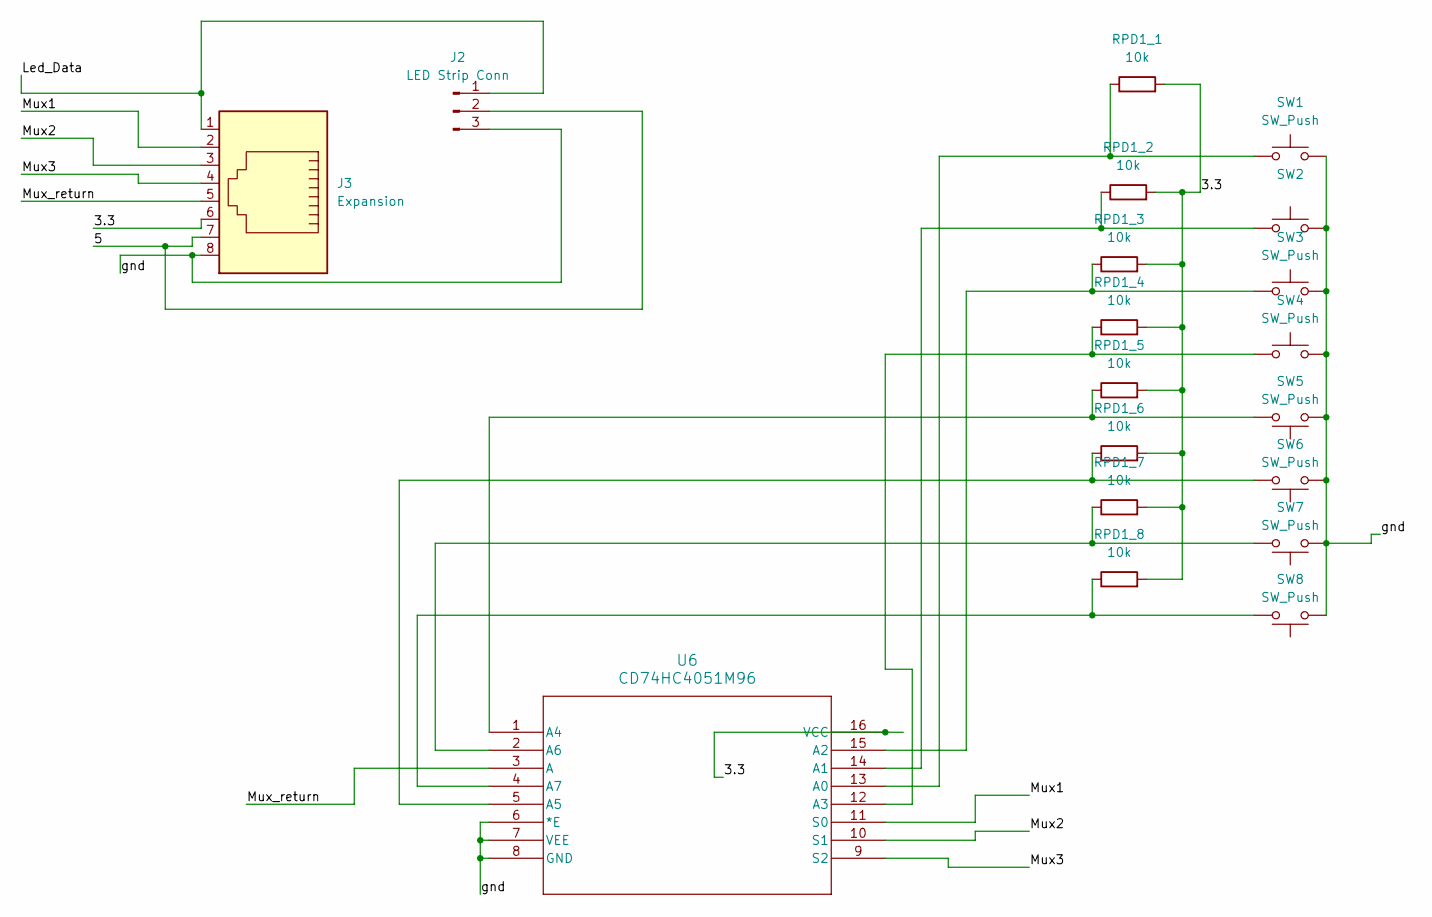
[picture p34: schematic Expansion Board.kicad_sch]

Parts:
J2: LED Strip Conn; PinHeader_1x03_P2.54mm_Vertical
J3: Expansion; RJ45_Amphenol_54602-x08_Horizontal
RPD1_1, RPD1_2, RPD1_3, RPD1_4, RPD1_5, RPD1_6, RPD1_7, RPD1_8: 10k; R_0805_2012Metric_Pad1.20x1.40mm_HandSolder
SW1, SW3, SW4, SW5, SW6, SW7, SW8: SW_Push; TerminalBlock_4Ucon_1x02_P3.50mm_Vertical
SW2: TerminalBlock_4Ucon_1x02_P3.50mm_Vertical
U6: CD74HC4051M96; QSOP-16_3.9x4.9mm_P0.635mm

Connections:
/3.3: J3.6, RPD1_1.2, RPD1_2.2, RPD1_3.2, RPD1_4.2, RPD1_5.2, RPD1_6.2, RPD1_7.2, RPD1_8.2, U6.16 (VCC)
/5: J2.2, J3.7
/Led_Data: J2.1, J3.1
/Mux1: J3.2, U6.11 (S0)
/Mux2: J3.3, U6.10 (S1)
/Mux3: J3.4, U6.9 (S2)
/Mux_return: J3.5, U6.3 (A)
/gnd: J2.3, J3.8, SW1.2, SW2.2, SW3.2, SW4.2, SW5.1, SW6.1, SW7.1, SW8.1, U6.6 (*E), U6.7 (VEE), U6.8 (GND)
unnamed: RPD1_1.1, SW1.1, U6.13 (A0)
unnamed: RPD1_2.1, SW2.1, U6.14 (A1)
unnamed: RPD1_3.1, SW3.1, U6.15 (A2)
unnamed: RPD1_4.1, SW4.1, U6.12 (A3)
unnamed: RPD1_5.1, SW5.2, U6.1 (A4)
unnamed: RPD1_6.1, SW6.2, U6.5 (A5)
unnamed: RPD1_7.1, SW7.2, U6.2 (A6)
unnamed: RPD1_8.1, SW8.2, U6.4 (A7)

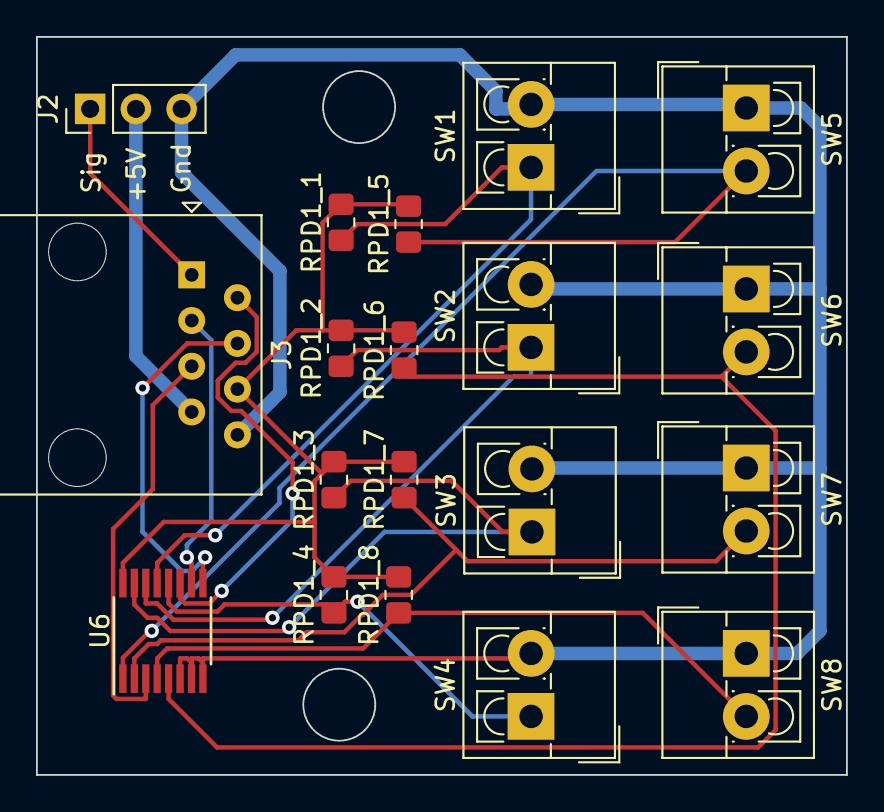
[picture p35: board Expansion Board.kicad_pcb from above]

Board: 2 copper layers, 45.0 x 41.0 mm, 19 parts (0 on the bottom side), 16 nets.

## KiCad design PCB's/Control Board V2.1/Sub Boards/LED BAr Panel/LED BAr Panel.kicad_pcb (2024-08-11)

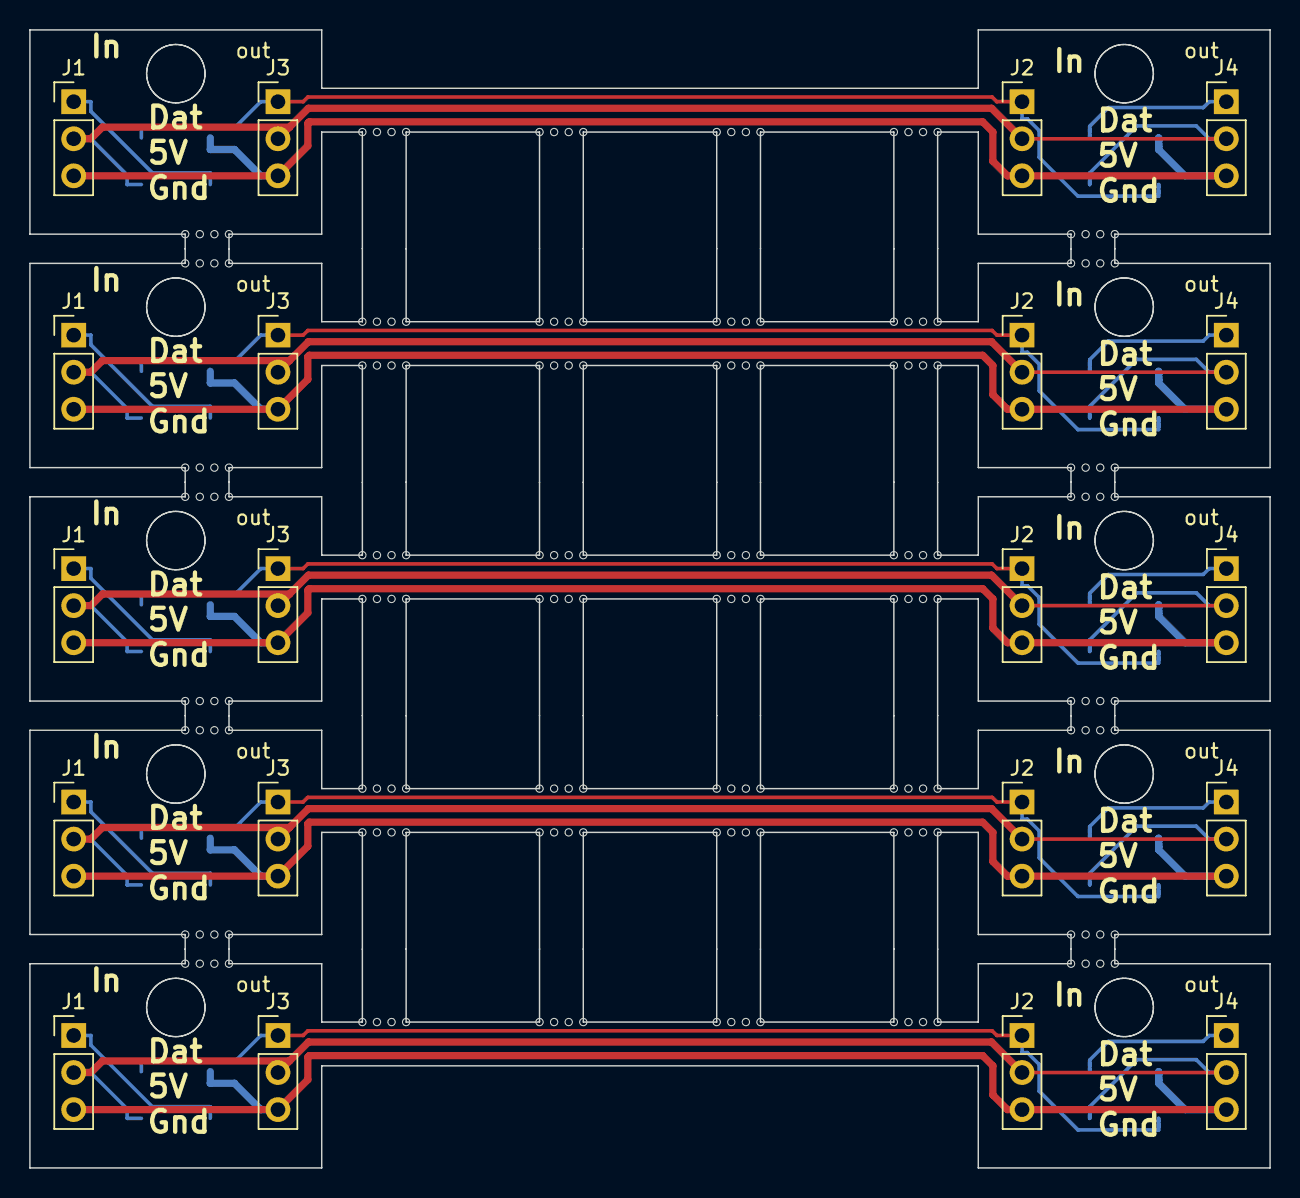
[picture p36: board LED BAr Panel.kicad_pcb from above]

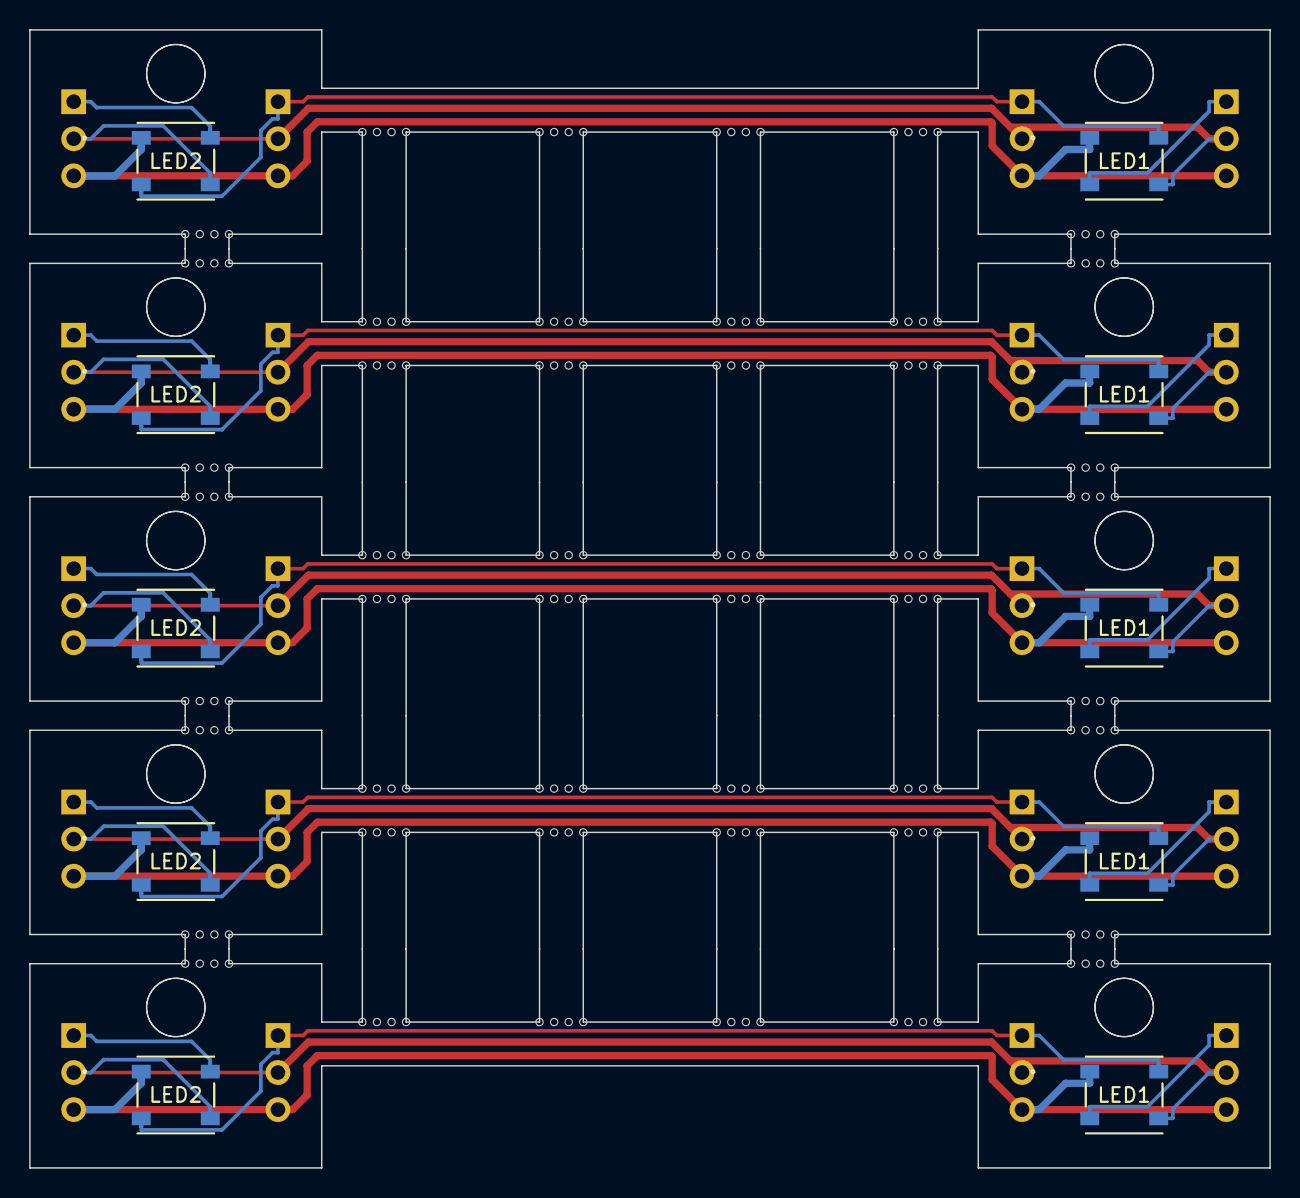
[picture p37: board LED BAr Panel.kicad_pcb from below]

Board: 2 copper layers, 85.0 x 78.0 mm, 222 parts (10 on the bottom side), 25 nets.

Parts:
J1, J1#2, J1#3, J1#4, J1#5, J3, J3#2, J3#3, J3#4, J3#5: LED Strip Conn; PinHeader_1x03_P2.54mm_Vertical
J2, J2#2, J2#3, J2#4, J2#5, J4, J4#2, J4#3, J4#4, J4#5: Conn_01x03_Socket; PinHeader_1x03_P2.54mm_Vertical
KiKit_MB_1_1, KiKit_MB_1_2, KiKit_MB_1_3, KiKit_MB_1_4, KiKit_MB_2_1, KiKit_MB_2_2, KiKit_MB_2_3, KiKit_MB_2_4, KiKit_MB_3_1, KiKit_MB_3_2, KiKit_MB_3_3, KiKit_MB_3_4, KiKit_MB_4_1, KiKit_MB_4_2, KiKit_MB_4_3, KiKit_MB_4_4, KiKit_MB_5_1, KiKit_MB_5_2, KiKit_MB_5_3, KiKit_MB_5_4, KiKit_MB_6_1, KiKit_MB_6_2, KiKit_MB_6_3, KiKit_MB_6_4, KiKit_MB_7_1, KiKit_MB_7_2, KiKit_MB_7_3, KiKit_MB_7_4, KiKit_MB_8_1, KiKit_MB_8_2, KiKit_MB_8_3, KiKit_MB_8_4, KiKit_MB_9_1, KiKit_MB_9_2, KiKit_MB_9_3, KiKit_MB_9_4, KiKit_MB_10_1, KiKit_MB_10_2, KiKit_MB_10_3, KiKit_MB_10_4, KiKit_MB_11_1, KiKit_MB_11_2, KiKit_MB_11_3, KiKit_MB_11_4, KiKit_MB_12_1, KiKit_MB_12_2, KiKit_MB_12_3, KiKit_MB_12_4, KiKit_MB_13_1, KiKit_MB_13_2, KiKit_MB_13_3, KiKit_MB_13_4, KiKit_MB_14_1, KiKit_MB_14_2, KiKit_MB_14_3, KiKit_MB_14_4, KiKit_MB_15_1, KiKit_MB_15_2, KiKit_MB_15_3, KiKit_MB_15_4, KiKit_MB_16_1, KiKit_MB_16_2, KiKit_MB_16_3, KiKit_MB_16_4, KiKit_MB_17_1, KiKit_MB_17_2, KiKit_MB_17_3, KiKit_MB_17_4, KiKit_MB_18_1, KiKit_MB_18_2, KiKit_MB_18_3, KiKit_MB_18_4, KiKit_MB_19_1, KiKit_MB_19_2, KiKit_MB_19_3, KiKit_MB_19_4, KiKit_MB_20_1, KiKit_MB_20_2, KiKit_MB_20_3, KiKit_MB_20_4, KiKit_MB_21_1, KiKit_MB_21_2, KiKit_MB_21_3, KiKit_MB_21_4, KiKit_MB_22_1, KiKit_MB_22_2, KiKit_MB_22_3, KiKit_MB_22_4, KiKit_MB_23_1, KiKit_MB_23_2, KiKit_MB_23_3, KiKit_MB_23_4, KiKit_MB_24_1, KiKit_MB_24_2, KiKit_MB_24_3, KiKit_MB_24_4, KiKit_MB_25_1, KiKit_MB_25_2, KiKit_MB_25_3, KiKit_MB_25_4, KiKit_MB_26_1, KiKit_MB_26_2, KiKit_MB_26_3, KiKit_MB_26_4, KiKit_MB_27_1, KiKit_MB_27_2, KiKit_MB_27_3, KiKit_MB_27_4, KiKit_MB_28_1, KiKit_MB_28_2, KiKit_MB_28_3, KiKit_MB_28_4, KiKit_MB_29_1, KiKit_MB_29_2, KiKit_MB_29_3, KiKit_MB_29_4, KiKit_MB_30_1, KiKit_MB_30_2, KiKit_MB_30_3, KiKit_MB_30_4, KiKit_MB_31_1, KiKit_MB_31_2, KiKit_MB_31_3, KiKit_MB_31_4, KiKit_MB_32_1, KiKit_MB_32_2, KiKit_MB_32_3, KiKit_MB_32_4, KiKit_MB_33_1, KiKit_MB_33_2, KiKit_MB_33_3, KiKit_MB_33_4, KiKit_MB_34_1, KiKit_MB_34_2, KiKit_MB_34_3, KiKit_MB_34_4, KiKit_MB_35_1, KiKit_MB_35_2, KiKit_MB_35_3, KiKit_MB_35_4, KiKit_MB_36_1, KiKit_MB_36_2, KiKit_MB_36_3, KiKit_MB_36_4, KiKit_MB_37_1, KiKit_MB_37_2, KiKit_MB_37_3, KiKit_MB_37_4, KiKit_MB_38_1, KiKit_MB_38_2, KiKit_MB_38_3, KiKit_MB_38_4, KiKit_MB_39_1, KiKit_MB_39_2, KiKit_MB_39_3, KiKit_MB_39_4, KiKit_MB_40_1, KiKit_MB_40_2, KiKit_MB_40_3, KiKit_MB_40_4, KiKit_MB_41_1, KiKit_MB_41_2, KiKit_MB_41_3, KiKit_MB_41_4, KiKit_MB_42_1, KiKit_MB_42_2, KiKit_MB_42_3, KiKit_MB_42_4, KiKit_MB_43_1, KiKit_MB_43_2, KiKit_MB_43_3, KiKit_MB_43_4, KiKit_MB_44_1, KiKit_MB_44_2, KiKit_MB_44_3, KiKit_MB_44_4, KiKit_MB_45_1, KiKit_MB_45_2, KiKit_MB_45_3, KiKit_MB_45_4, KiKit_MB_46_1, KiKit_MB_46_2, KiKit_MB_46_3, KiKit_MB_46_4, KiKit_MB_47_1, KiKit_MB_47_2, KiKit_MB_47_3, KiKit_MB_47_4, KiKit_MB_48_1, KiKit_MB_48_2, KiKit_MB_48_3, KiKit_MB_48_4: NPTH
LED1, LED1#2, LED1#3, LED1#4, LED1#5, LED2, LED2#2, LED2#3, LED2#4, LED2#5: IN-PI55TATPRPGPB; LED_IN-PI55TAT_INL

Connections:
Board_0-+5V: J1#2.2, J2#3.2, J3#2.2, J4#5.2, LED1#4.4 (VDD), LED2#4.4 (VDD)
Board_0-/A: J2#3.1, J3#2.1, LED1#4.2 (DOUT), LED2#4.3 (DIN)
Board_0-/B: J4#5.1, LED2#4.2 (DOUT)
Board_0-GND: J1#2.3, J2#3.3, J3#2.3, J4#5.3, LED1#4.1 (GND), LED2#4.1 (GND)
Board_0-Net-(J1-Pin_1): J1#2.1, LED1#4.3 (DIN)
Board_1-+5V: J1#4.2, J2#5.2, J3#3.2, J4#2.2, LED1#5.4 (VDD), LED2.4 (VDD)
Board_1-/A: J2#5.1, J3#3.1, LED1#5.2 (DOUT), LED2.3 (DIN)
Board_1-/B: J4#2.1, LED2.2 (DOUT)
Board_1-GND: J1#4.3, J2#5.3, J3#3.3, J4#2.3, LED1#5.1 (GND), LED2.1 (GND)
Board_1-Net-(J1-Pin_1): J1#4.1, LED1#5.3 (DIN)
Board_2-+5V: J1.2, J2#2.2, J3#4.2, J4.2, LED1.4 (VDD), LED2#2.4 (VDD)
Board_2-/A: J2#2.1, J3#4.1, LED1.2 (DOUT), LED2#2.3 (DIN)
Board_2-/B: J4.1, LED2#2.2 (DOUT)
Board_2-GND: J1.3, J2#2.3, J3#4.3, J4.3, LED1.1 (GND), LED2#2.1 (GND)
Board_2-Net-(J1-Pin_1): J1.1, LED1.3 (DIN)
Board_3-+5V: J1#3.2, J2.2, J3#5.2, J4#4.2, LED1#2.4 (VDD), LED2#5.4 (VDD)
Board_3-/A: J2.1, J3#5.1, LED1#2.2 (DOUT), LED2#5.3 (DIN)
Board_3-/B: J4#4.1, LED2#5.2 (DOUT)
Board_3-GND: J1#3.3, J2.3, J3#5.3, J4#4.3, LED1#2.1 (GND), LED2#5.1 (GND)
Board_3-Net-(J1-Pin_1): J1#3.1, LED1#2.3 (DIN)
Board_4-+5V: J1#5.2, J2#4.2, J3.2, J4#3.2, LED1#3.4 (VDD), LED2#3.4 (VDD)
Board_4-/A: J2#4.1, J3.1, LED1#3.2 (DOUT), LED2#3.3 (DIN)
Board_4-/B: J4#3.1, LED2#3.2 (DOUT)
Board_4-GND: J1#5.3, J2#4.3, J3.3, J4#3.3, LED1#3.1 (GND), LED2#3.1 (GND)
Board_4-Net-(J1-Pin_1): J1#5.1, LED1#3.3 (DIN)

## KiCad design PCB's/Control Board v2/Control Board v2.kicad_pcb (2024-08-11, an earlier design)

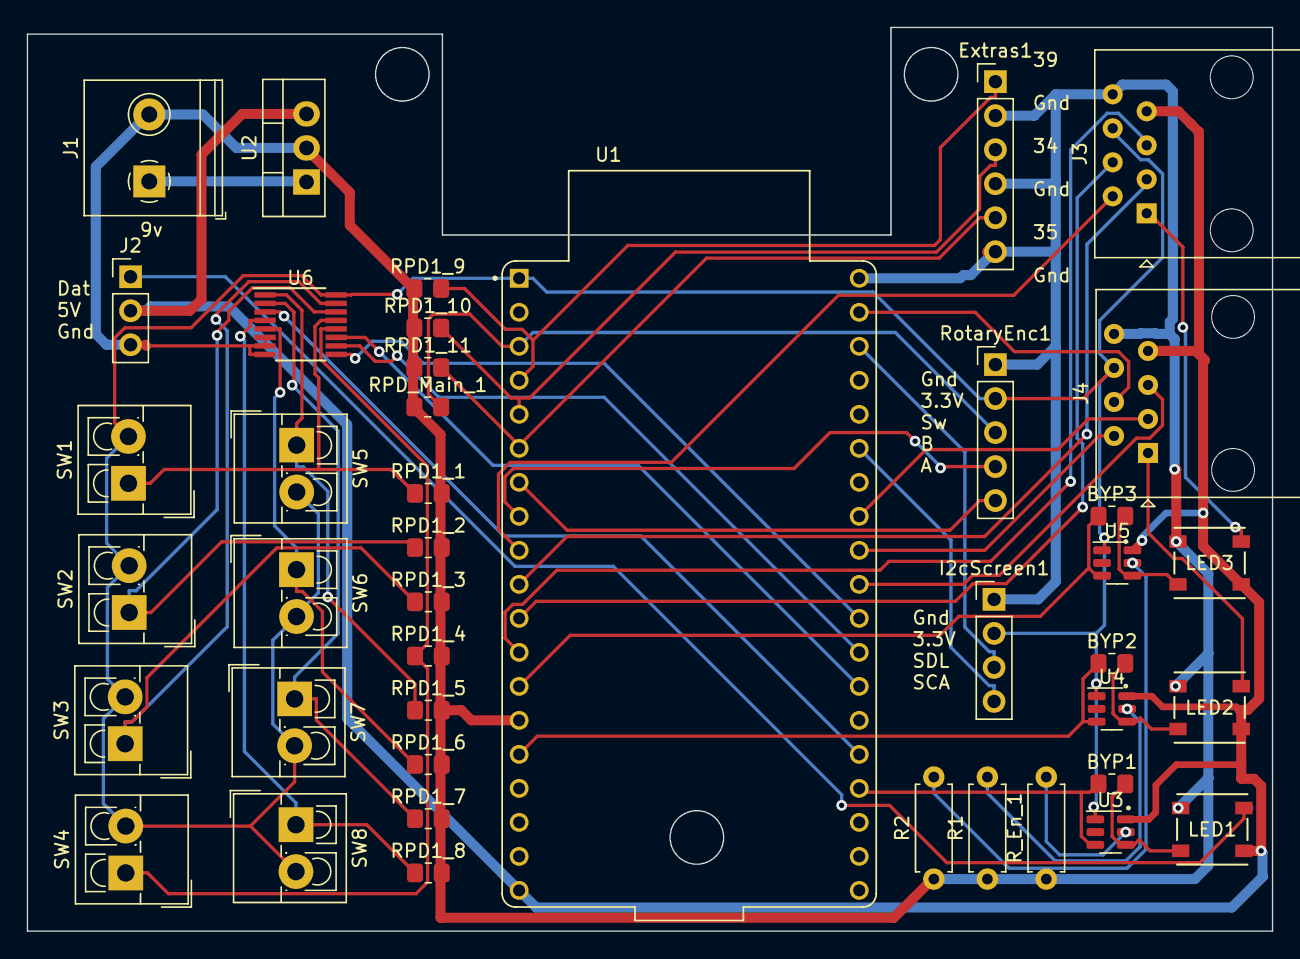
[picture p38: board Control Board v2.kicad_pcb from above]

Board: 2 copper layers, 93.0 x 67.5 mm, 42 parts (0 on the bottom side), 44 nets.

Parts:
BYP1, BYP2, BYP3: R_0805_2012Metric_Pad1.20x1.40mm_HandSolder
Extras1: Conn_01x06_Pin; PinHeader_1x06_P2.54mm_Vertical
I2cScreen1: Conn_01x05_Pin; PinHeader_1x04_P2.54mm_Vertical
J1: Power In; TerminalBlock_Philmore_TB132_1x02_P5.00mm_Horizontal
J2: LED Strip Conn; PinHeader_1x03_P2.54mm_Vertical
J3, J4: Expansion; RJ45_Amphenol_54602-x08_Horizontal
LED1, LED2, LED3: IN-PI55TATPRPGPB; LED_IN-PI55TAT_INL
R1, R2: R; R_Axial_DIN0207_L6.3mm_D2.5mm_P7.62mm_Horizontal
RPD1_1, RPD1_2, RPD1_3, RPD1_4, RPD1_5, RPD1_6, RPD1_7, RPD1_8, RPD1_9, RPD1_10, RPD1_11: 10k; R_0805_2012Metric_Pad1.20x1.40mm_HandSolder
RPD_Main_1: 10k; R_0805_2012Metric_Pad1.20x1.40mm_HandSolder
R_En_1: R; R_Axial_DIN0207_L6.3mm_D2.5mm_P7.62mm_Horizontal
RotaryEnc1: Conn_01x05_Pin; PinHeader_1x05_P2.54mm_Vertical
SW1, SW2, SW3, SW4, SW5, SW6, SW7, SW8: SW_Push; TerminalBlock_4Ucon_1x02_P3.50mm_Vertical
U1: ESP32-DEVKITC-32E; MODULE_ESP32-DEVKITC-32E
U2: L7805; TO-220-3_Vertical
U3, U4, U5: TXS0101DBV; SOT-23-6
U6: CD74HC4051M96; QSOP-16_3.9x4.9mm_P0.635mm

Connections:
+3.3V: I2cScreen1.2, J3.6, J4.6, RotaryEnc1.2, SW1.2, SW2.2, SW3.2, SW4.2, SW5.2, SW6.2, SW7.2, SW8.2, U1.J2_1 (3V3), U3.1 (V_{CCA}), U4.1 (V_{CCA}), U5.1 (V_{CCA}), U6.16 (VCC)
+5V: J2.2, J3.7, J4.7, LED1.4 (VDD), LED2.4 (VDD), LED3.4 (VDD), U1.J2_19 (EXT_5V), U2.3 (OUT), U3.6 (V_{CCB}), U4.6 (V_{CCB}), U5.6 (V_{CCB})
+9V: J1.1, U2.1 (IN)
/Enc_A: RotaryEnc1.5, U1.J2_7 (IO32)
/Enc_B: RotaryEnc1.4, U1.J2_8 (IO33)
/Enc_Sw: RPD_Main_1.2, RotaryEnc1.3, U1.J2_3 (SENSOR_VP)
/GP34: Extras1.3, RPD1_10.2, U1.J2_5 (IO34)
/GP35: Extras1.5, RPD1_11.2, U1.J2_6 (IO35)
/GP39: Extras1.1, RPD1_9.2, U1.J2_4 (SENSOR_VN)
/I2C_SCL: I2cScreen1.3, U1.J3_3 (IO22)
/I2C_SDA: I2cScreen1.4, U1.J3_6 (IO21)
/Mux2_1: J4.2, U1.J3_9 (IO18)
/Mux2_2: J4.3, U1.J3_8 (IO19)
/Mux2_3: J4.4, U1.J3_2 (IO23)
/Mux2_return: J4.5, U1.J3_10 (IO5)
/Mux3_1: J3.2, U1.J2_9 (IO25)
/Mux3_2: J3.3, U1.J2_10 (IO26)
/Mux3_3: J3.4, U1.J2_11 (IO27)
/Mux3_return: J3.5, U1.J2_12 (IO14)
GND: Extras1.2, Extras1.4, Extras1.6, I2cScreen1.1, J1.2, J2.3, J3.8, J4.8, LED1.1 (GND), LED2.1 (GND), LED3.1 (GND), R1.1, R2.1, RPD1_1.2, RPD1_2.2, RPD1_3.2, RPD1_4.2, RPD1_5.2, RPD1_6.2, RPD1_7.2, RPD1_8.2, RPD1_9.1, RPD1_10.1, RPD1_11.1, RPD_Main_1.1, R_En_1.1, RotaryEnc1.1, U1.J2_14 (GND_J2_14), U1.J3_1 (GND_J3_1), U2.2 (GND), U6.6 (*E), U6.7 (VEE), U6.8 (GND)
LED_1_Data: J2.1, LED1.2 (DOUT)
LED_1_sig: BYP1.1, U1.J3_16 (IO15), U3.3 (A)
LED_2_Data: J4.1, LED2.2 (DOUT)
LED_2_sig: BYP2.1, U1.J2_15 (IO13), U4.3 (A)
LED_3_Data: J3.1, LED3.2 (DOUT)
LED_3_sig: BYP3.1, U1.J2_13 (IO12), U5.3 (A)
Mux1_1: U1.J3_13 (IO4), U6.11 (S0)
Mux1_2: U1.J3_12 (IO16), U6.10 (S1)
Mux1_3: U1.J3_11 (IO17), U6.9 (S2)
Mux1_return: U1.J3_15 (IO2), U6.3 (A)
unnamed: BYP1.2, LED1.3 (DIN), U3.4 (B)
unnamed: BYP2.2, LED2.3 (DIN), U4.4 (B)
unnamed: BYP3.2, LED3.3 (DIN), U5.4 (B)
unnamed: R_En_1.2, U3.5 (OE)
unnamed: R1.2, U4.5 (OE)
unnamed: R2.2, U5.5 (OE)
unnamed: RPD1_1.1, SW1.1, U6.13 (A0)
unnamed: RPD1_2.1, SW2.1, U6.14 (A1)
unnamed: RPD1_3.1, SW3.1, U6.15 (A2)
unnamed: RPD1_4.1, SW4.1, U6.12 (A3)
unnamed: RPD1_5.1, SW5.1, U6.1 (A4)
unnamed: RPD1_6.1, SW6.1, U6.5 (A5)
unnamed: RPD1_7.1, SW7.1, U6.2 (A6)
unnamed: RPD1_8.1, SW8.1, U6.4 (A7)

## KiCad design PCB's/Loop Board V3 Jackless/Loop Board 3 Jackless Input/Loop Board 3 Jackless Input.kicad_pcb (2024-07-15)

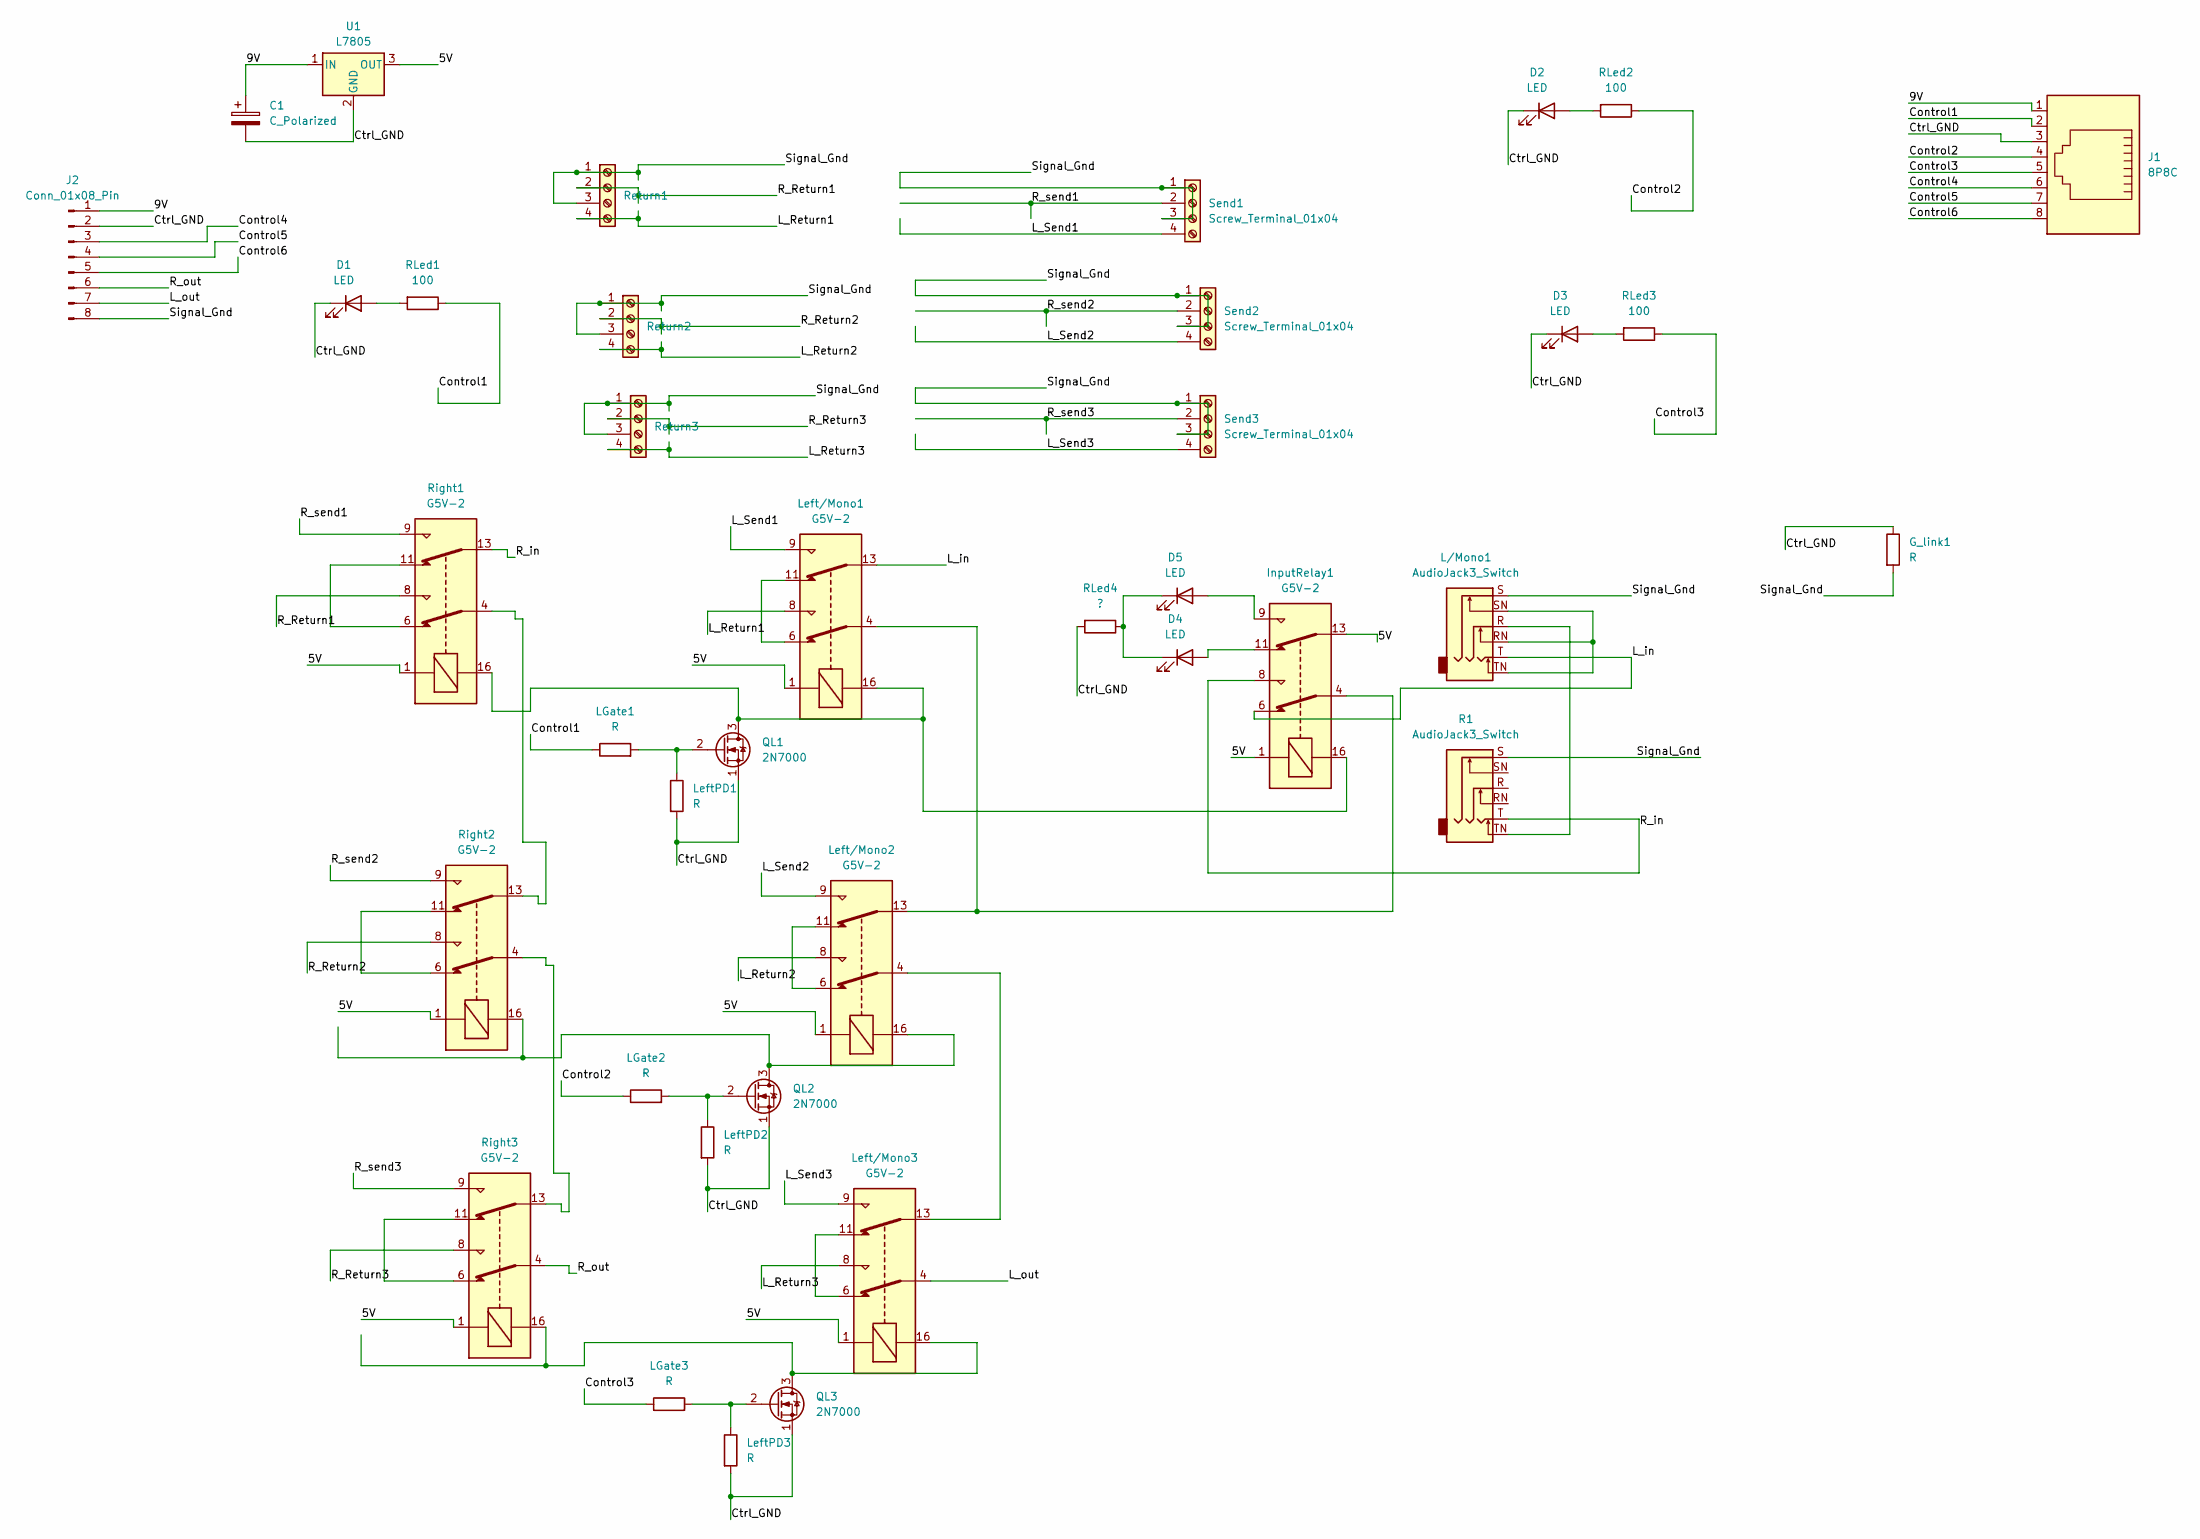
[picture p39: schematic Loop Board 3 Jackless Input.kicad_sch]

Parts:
C1: C_Polarized; CP_Radial_D10.0mm_P3.50mm
D1, D2, D3, D4, D5: LED; LED_D5.0mm
G_link1: R; R_0805_2012Metric
InputRelay1: G5V-2; Relay_DPDT_Omron_G5V-2
J1: 8P8C; RJ45_Amphenol_54602-x08_Horizontal
J2: Conn_01x08_Pin; PinSocket_1x08_P2.54mm_Vertical
L/Mono1: AudioJack3_Switch; Jack_6.35mm_Neutrik_NMJ6HCD2_Horizontal
LGate1, LGate2, LGate3: R; R_Axial_DIN0207_L6.3mm_D2.5mm_P7.62mm_Horizontal
Left/Mono1, Left/Mono2, Left/Mono3: G5V-2; Relay_DPDT_Omron_G5V-2
LeftPD1, LeftPD2, LeftPD3: R; R_Axial_DIN0207_L6.3mm_D2.5mm_P7.62mm_Horizontal
QL1, QL2, QL3: 2N7000; TO-92_Inline
R1: AudioJack3_Switch; Jack_6.35mm_Neutrik_NMJ6HCD2_Horizontal
RLed1, RLed2, RLed3: 100; R_Axial_DIN0207_L6.3mm_D2.5mm_P7.62mm_Horizontal
RLed4: ?; R_Axial_DIN0207_L6.3mm_D2.5mm_P7.62mm_Horizontal
Return1, Return2, Return3: Screw_Terminal_01x04; CUI_TB001-500-04BE
Right1, Right2, Right3: G5V-2; Relay_DPDT_Omron_G5V-2
Send1, Send2, Send3: Screw_Terminal_01x04; CUI_TB001-500-04BE
U1: L7805; TO-220-3_Vertical

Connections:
/5V: InputRelay1.1, InputRelay1.13, Left/Mono1.1, Left/Mono2.1, Left/Mono3.1, Right1.1, Right2.1, Right3.1, U1.3 (OUT)
/9V: C1.1, J1.1, J2.1, U1.1 (IN)
/Control1: J1.2, LGate1.1, RLed1.1
/Control2: J1.4, LGate2.1, RLed2.1
/Control3: J1.5, LGate3.1, RLed3.1
/Control4: J1.6, J2.3
/Control5: J1.7, J2.4
/Control6: J1.8, J2.5
/Ctrl_GND: C1.2, D1.1 (K), D2.1 (K), D3.1 (K), G_link1.1, J1.3, J2.2, LeftPD1.2, LeftPD2.2, LeftPD3.2, QL1.1 (S), QL2.1 (S), QL3.1 (S), RLed4.2, U1.2 (GND)
/L_Return1: Left/Mono1.8, Return1.4
/L_Return2: Left/Mono2.8, Return2.4
/L_Return3: Left/Mono3.8, Return3.4
/L_Send1: Left/Mono1.9, Send1.4
/L_Send2: Left/Mono2.9, Send2.4
/L_Send3: Left/Mono3.9, Send3.4
/L_in: InputRelay1.6, L/Mono1.T, Left/Mono1.13
/L_out: J2.7, Left/Mono3.4
/R_Return1: Return1.2, Right1.8
/R_Return2: Return2.2, Right2.8
/R_Return3: Return3.2, Right3.8
/R_in: InputRelay1.8, R1.T, Right1.13
/R_out: J2.6, Right3.4
/R_send1: Right1.9, Send1.2
/R_send2: Right2.9, Send2.2
/R_send3: Right3.9, Send3.2
/Signal_Gnd: G_link1.2, J2.8, L/Mono1.S, R1.S, Return1.1, Return1.3, Return2.1, Return2.3, Return3.1, Return3.3, Send1.1, Send1.3, Send2.1, Send2.3, Send3.1, Send3.3
unnamed: D1.2 (A), RLed1.2
unnamed: D2.2 (A), RLed2.2
unnamed: D3.2 (A), RLed3.2
unnamed: D4.2 (A), InputRelay1.11
unnamed: D4.1 (K), D5.1 (K), RLed4.1
unnamed: D5.2 (A), InputRelay1.9
unnamed: InputRelay1.4, Left/Mono1.4, Left/Mono2.13
unnamed: L/Mono1.R, R1.TN
unnamed: L/Mono1.RN, L/Mono1.SN, L/Mono1.TN
unnamed: Left/Mono1.6, Left/Mono1.11
unnamed: Left/Mono2.4, Left/Mono3.13
unnamed: Left/Mono2.6, Left/Mono2.11
unnamed: Left/Mono3.6, Left/Mono3.11
unnamed: InputRelay1.16, Left/Mono1.16, QL1.3 (D), Right1.16
unnamed: LGate1.2, LeftPD1.1, QL1.2 (G)
unnamed: Left/Mono2.16, QL2.3 (D), Right2.16
unnamed: LGate2.2, LeftPD2.1, QL2.2 (G)
unnamed: Left/Mono3.16, QL3.3 (D), Right3.16
unnamed: LGate3.2, LeftPD3.1, QL3.2 (G)
unnamed: Right1.4, Right2.13
unnamed: Right1.6, Right1.11
unnamed: Right2.4, Right3.13
unnamed: Right2.6, Right2.11
unnamed: Right3.6, Right3.11

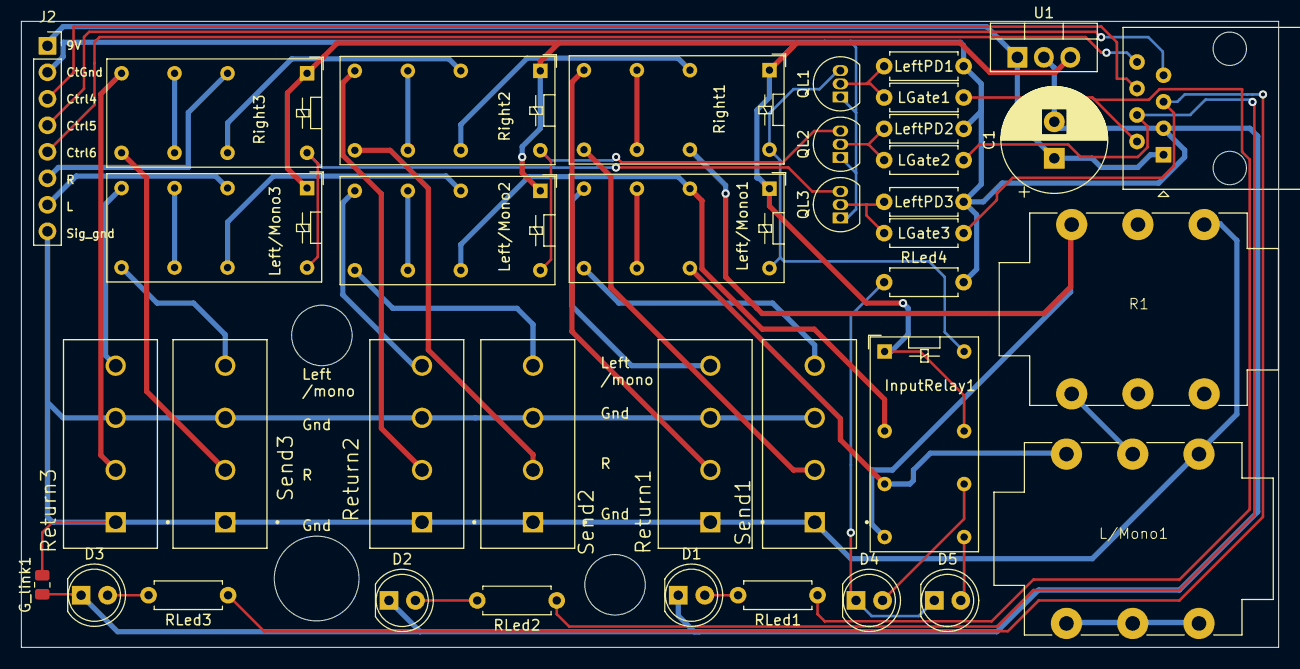
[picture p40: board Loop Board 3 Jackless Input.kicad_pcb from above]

Board: 2 copper layers, 120.5 x 60.0 mm, 38 parts (0 on the bottom side), 50 nets.

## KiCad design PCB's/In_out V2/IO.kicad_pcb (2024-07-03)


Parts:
A1: AudioJack3_Switch; Jack_6.35mm_Neutrik_NMJ6HFD3_Horizontal
B1: AudioJack3_Switch; Jack_6.35mm_Neutrik_NMJ6HFD3_Horizontal
C1: C_Polarized; CP_Radial_D10.0mm_P3.50mm
D2: LEDA; LED_D5.0mm
J1: Conn_01x01_Pin; PinHeader_1x01_P2.54mm_Vertical
J2, J3: Conn_01x02_Pin; PinHeader_2x01_P2.54mm_Vertical
LEDB1: LED; LED_D5.0mm
Left/Mono1: G5V-2; Relay_DPDT_Omron_G5V-2
Out1, Out2, Out3: Conn_01x03_Pin; PinHeader_1x03_P2.54mm_Vertical
QL1: 2N7000; TO-92_Inline
RGate1: R; R_Axial_DIN0207_L6.3mm_D2.5mm_P7.62mm_Horizontal
RLed1, RLed2: R; R_Axial_DIN0207_L6.3mm_D2.5mm_P7.62mm_Horizontal
RPD1: R; R_Axial_DIN0207_L6.3mm_D2.5mm_P7.62mm_Horizontal
U1: L7805; TO-220-3_Vertical

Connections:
/5V: Left/Mono1.13, Left/Mono1.16, U1.3 (OUT)
/9V: C1.1, J2.1, J3.1, U1.1 (IN)
/A: A1.T, Left/Mono1.6, Out2.2
/B: B1.T, Left/Mono1.8, Out3.2
/Control: J1.1, RGate1.1
/Ctrl_GND: C1.2, D2.1 (K), J2.2, J3.2, LEDB1.1 (K), QL1.1 (S), RPD1.2, U1.2 (GND)
/L_out: Left/Mono1.4, Out1.2, Out1.3
/Signal_Gnd: A1.S, B1.S, Out1.1, Out2.1, Out3.1
unnamed: A1.RN, A1.SN, A1.TN
unnamed: B1.RN, B1.SN, B1.TN
unnamed: D2.2 (A), RLed2.2
unnamed: LEDB1.2 (A), RLed1.2
unnamed: Left/Mono1.9, RLed1.1
unnamed: Left/Mono1.11, RLed2.1
unnamed: A1.R, Out2.3
unnamed: B1.R, Out3.3
unnamed: Left/Mono1.1, QL1.3 (D)
unnamed: QL1.2 (G), RGate1.2, RPD1.1



Board: 2 copper layers, 51.7 x 42.3 mm, 18 parts (2 on the bottom side), 18 nets.

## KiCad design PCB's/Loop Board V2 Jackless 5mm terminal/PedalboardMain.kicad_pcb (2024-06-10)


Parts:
D1: LED; LED_D5.0mm
In1: Conn_01x03_Pin; PinHeader_1x03_P2.54mm_Vertical
J1: Conn_01x01_Pin; PinHeader_1x01_P2.54mm_Vertical
J2, J3: Conn_01x02_Pin; PinHeader_2x01_P2.54mm_Vertical
J4, J5: Screw_Terminal_01x04; CUI_TB001-500-04BE
LGate1: R; R_Axial_DIN0207_L6.3mm_D2.5mm_P7.62mm_Horizontal
Left/Mono1: G5V-2; Relay_DPDT_Omron_G5V-2
LeftPD1: R; R_Axial_DIN0207_L6.3mm_D2.5mm_P7.62mm_Horizontal
Out1: Conn_01x03_Pin; PinHeader_1x03_P2.54mm_Vertical
QL1: 2N7000; TO-92_Inline
RLed1: 100; R_Axial_DIN0207_L6.3mm_D2.5mm_P7.62mm_Horizontal
Right1: G5V-2; Relay_DPDT_Omron_G5V-2
U1: L7805; TO-220-3_Vertical

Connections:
/5V: Left/Mono1.1, Right1.1, U1.3 (OUT)
/9V: J2.1, J3.1, U1.1 (IN)
/Control: J1.1, LGate1.1, RLed1.1
/Ctrl_GND: D1.1 (K), J2.2, J3.2, LeftPD1.2, QL1.1 (S), U1.2 (GND)
/L_Return: J4.4, Left/Mono1.8
/L_Send: J5.4, Left/Mono1.9
/L_in: In1.2, Left/Mono1.13
/L_out: Left/Mono1.4, Out1.2
/R_Return: J4.2, Right1.8
/R_in: In1.3, Right1.13
/R_out: Out1.3, Right1.4
/R_send: J5.2, Right1.9
/Signal_Gnd: In1.1, J4.1, J4.3, J5.1, J5.3, Out1.1
unnamed: D1.2 (A), RLed1.2
unnamed: Left/Mono1.6, Left/Mono1.11
unnamed: Left/Mono1.16, QL1.3 (D), Right1.16
unnamed: LGate1.2, LeftPD1.1, QL1.2 (G)
unnamed: Right1.6, Right1.11


Board: 2 copper layers, 63.3 x 26.0 mm, 15 parts (0 on the bottom side), 18 nets.

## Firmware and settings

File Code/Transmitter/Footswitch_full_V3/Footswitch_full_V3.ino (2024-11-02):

#include <Adafruit_GFX.h>
#include <Adafruit_SSD1306.h>
#include <esp_now.h>
#include <WiFi.h>
#include <FastLED.h>

// OLED display setup
#define SCREEN_WIDTH 128
#define SCREEN_HEIGHT 64
#define OLED_RESET    -1
#define screen_switch_time 0
Adafruit_SSD1306 display(SCREEN_WIDTH, SCREEN_HEIGHT, &Wire, OLED_RESET);
const bool loops_m1[6] = {0,0,0,0,0,0};
const bool loops_m2[6] = {0,0,0,0,0,0};
const bool loops_m3[6] = {0,0,0,0,0,0};

bool loops[19] = {0,loops_m1,loops_m2,loops_m3};
unsigned long timers[4]={0,0,0,0};

const int push_array[2][8] = {{1,3,5,8,9,10,11,12},{0,0,0,0,0,0,0,0}};  //put loop number to be switched by a given switch, first array is main, second is expansion.
const int hold_array[2][8] = {{2,4,6,7,0,0,0,0},{0,0,0,0,0,0,0,0}}; //loop number on the press/hold function on a given Loop, 0 should mean no hold function
const bool toggle_mode[2][8] = {{true,true,true,true,true,false,false,false},{false,false,false,false,false,false,false,false}};  //true means when hold active, the push controls the hold pedal,  false means push controls 1, hold controls the other.
bool mode_state[2][8] = {{false,false,false,false,false,false,false,false},{false,false,false,false,false,false,false,false}}; //false for hold inactive, true for hold active.
#define LED_DATA_PIN_1 15
#define LED_DATA_PIN_2 12
#define LED_DATA_PIN_3 13
#define NUM_LEDS 9
#define NUM_STATES 6
CRGB leds_1[NUM_LEDS];
CRGB leds_2[NUM_LEDS];
CRGB leds_3[1];
const int pwr = 30;
const int red = 75;
int Switch_Status[2][NUM_LEDS] = {{0,0,0,0,0,0,0,0,0},{0,0,0,0,0,0,0,0,0}};// 0 for off, 1 for push on, 2 for hold active, 3 for hold on, 4 for both active, 5 for toggle off
int colors[NUM_STATES][3] = {{0,0,0},{red,0,0},{pwr,0,pwr},{0,0,pwr},{red,pwr,0},{0,pwr,0}};

const char* labels_m1[] = {"Face","Bender","Broadcast","Bad Bob","BlackBox","Revival"};
const char* labels_m2[] = {"Doppler","Flange","Volante","Megabyte","Tensor","Mercury"};
const char* labels_m3[] = {"E","E","E","E","E","E"};
const int label_count = 12;

typedef struct DataStruct {
  bool loop1;
  bool loop2;
  bool loop3;
  bool loop4;
  bool loop5;
  bool loop6;
  bool loop7;
  bool loop8;
  bool loop9;
  bool loop10;
  bool loop11;
  bool loop12;
  bool loop13;
  bool loop14;
  bool loop15;
  bool loop16;
  bool loop17;
  bool loop18;
  int Vol;
} DataStruct;
DataStruct Data;


#define SlaveCnt 3

// Structure to hold peer information
typedef struct {
  uint8_t peer_addr[6];
} SlaveInfo;

esp_now_peer_info_t peerInfo;

SlaveInfo slaves[SlaveCnt];

uint8_t broadcastAddresses[][6] = {
  {0xC8, 0x2E, 0x18, 0xEF, 0xE1, 0xE0}, // Light Test ESP
  {0x40, 0x22, 0xD8, 0x77, 0x15, 0xA4},
  {0xF0, 0xF5, 0xBD, 0x2D, 0x0D, 0x5C}, // Train Test ESP
};


// Rotary encoder setup
const int encoderPinA = 32;
const int encoderPinB = 33;
const int buttonPin = 36;
const int enc_speed = 3;
int count = 0;
// MUX control pins
const int error_thresh = 1;
const int hold_thresh = 10;
const int muxcount = 1;    
const int mux[2][6] = {
   {4,16,17,14,8,1},  
  {18,19,23,5,8,1}}; //disabled mux 3, and stole pin 14 for mux 1                 
  //{25,26,27,14,8,1}}; //Pin 1,2,3,return,switch count,delay(ms)  

const int volPin = 27;
int Vol = 100;

volatile bool state = 0;
volatile int adc = 1;
int mux_deb[2][8] = {{0,0,0,0,0,0,0,0},{0,0,0,0,0,0,0,0}};

// Debouncing variables
const unsigned long DEBOUNCE_DELAY = 10; // Debounce time in milliseconds
unsigned long lastDebounceTime = 0; // Last time the encoder state was checked
int lastEncoderState = LOW; // The previous state of the encoder

volatile int lastEncoderValue = 0;
volatile int encoderPosition[3] = {enc_speed, enc_speed, enc_speed};
volatile int screenPosition[3] = {1, 1, 1};

bool buttonState = false;
bool lastButtonState = false;
bool VolumeScreen = 0;
unsigned long screen_time = 0;

const int encodermax = label_count*enc_speed;

void IRAM_ATTR readEncoder() {
  unsigned long currentTime = millis();

  // Read encoder pins
  int MSB = digitalRead(encoderPinA); // MSB = most significant bit
  int LSB = digitalRead(encoderPinB); // LSB = least significant bit

  int encoded = (MSB << 1) | LSB; // converting the 2 pin value to a single number
  int sum = (lastEncoderValue << 2) | encoded; // adding it to the previous encoded value

  // Only update position if debounce time has passed
  if ((currentTime - lastDebounceTime) > DEBOUNCE_DELAY) {
    if (sum == 0b1101 || sum == 0b0100 || sum == 0b0010 || sum == 0b1011) encoderPosition[1]++;
    if (sum == 0b1110 || sum == 0b0111 || sum == 0b0001 || sum == 0b1000) encoderPosition[1]--;

    lastEncoderValue = encoded; // store this value for next time
    lastDebounceTime = currentTime; // Update the last debounce time
  }
}

void OnDataSent(const uint8_t *mac_addr, esp_now_send_status_t status) {
}

void setup() {
  Serial.begin(115200);
  delay(500);
  pinMode(buttonPin, INPUT);
  pinMode(encoderPinA, INPUT_PULLUP);
  pinMode(encoderPinB, INPUT_PULLUP);
  pinMode(volPin, INPUT);
  FastLED.addLeds<NEOPIXEL, LED_DATA_PIN_1>(leds_1, NUM_LEDS);
  FastLED.addLeds<NEOPIXEL, LED_DATA_PIN_2>(leds_2, NUM_LEDS);
  FastLED.addLeds<NEOPIXEL, LED_DATA_PIN_3>(leds_3, 1);
  leds_1[0] = CRGB(255,0,0);
  leds_2[0] = CRGB(0,255,0);
  leds_3[0] = CRGB(0,0,255);

  // Initialize MUX control pins  
  for(int k=0;k<muxcount;k++){
    for (int j=0;j<3;j++){
      pinMode(mux[k][j], OUTPUT);
    }
  //Mux signal return pins
  pinMode(mux[k][3], INPUT_PULLUP);
  }
  //pinMode(5,INPUT);

  attachInterrupt(digitalPinToInterrupt(encoderPinA), readEncoder, CHANGE);
  attachInterrupt(digitalPinToInterrupt(encoderPinB), readEncoder, CHANGE);

  // Initialize OLED
  if (!display.begin(SSD1306_SWITCHCAPVCC, 0x3C)) {
    Serial.println(F("SSD1306 allocation failed"));
    for (;;);
  }
  display.clearDisplay();
  display.display();
  display.setTextSize(1);
  display.setTextColor(SSD1306_WHITE);
  display.setCursor(0, 10);
  display.print("OLED & Encoder Working");
  display.display();

  // Initialize ESP-NOW
  WiFi.mode(WIFI_STA);
  if (esp_now_init() != ESP_OK) {
    Serial.println("Error initializing ESP-NOW");
    return;
  }
  esp_now_register_send_cb(OnDataSent);
  peerInfo.channel = 0;
  peerInfo.encrypt = false;

  for (int i = 0; i < SlaveCnt; i++) {
    memcpy(peerInfo.peer_addr, broadcastAddresses[i], 6);
    if (esp_now_add_peer(&peerInfo) != ESP_OK) {
      Serial.println("Failed to add peer");
      return;
    }
  }
  initLoopState();
  delay(500);
  PrintSerialString1();

  for(int z = 0; z < 6; z++){
  Serial.print(loops_m1[z]);
  Serial.print(loops_m2[z]);
  Serial.print(loops_m3[z]);
  Serial.print(" | ");}
    Serial.println();

  for(int x = 0; x < 19; x++){
  Serial.print(loops[x]);
  Serial.print(" | ");}
  Serial.println();
  esp_now_send(0, (uint8_t *)&Data, sizeof(DataStruct)); //send initial states
}


//---------------------------------------------------------------------------------------------------------
void loop() {
  unsigned long ct = millis();
  bool holdtrigger = false;
  int loop;

  //VolumeHandler();

  // Check MUX buttons
  if(VolumeScreen == true){VolumeHandler();}
  else{
  screenPosition[1] = encoderPosition[1] / enc_speed;}
  for (int j = 0; j < muxcount; j++) {
    for (int i = 0; i < mux[j][4]; i++) {
      if (readMuxButton(i, j)) {
        mux_deb[j][i] += 1;
      }

      //============Hold Engaged
      if (mux_deb[j][i] >= hold_thresh && hold_array[j][i] != 0) {
        
        mux_deb[j][i] = 0;
        holdtrigger = true;
        timers[1] = ct + 500;

        if (toggle_mode[j][i] == false) { // check for toggle, or push-hold function, this is push-hold.
          switch_status_control(j, i + 1, holdtrigger, false);
          loop = hold_array[j][i];
          screenPosition[2] = loop;
          encoderPosition[2] = screenPosition[2] * enc_speed;
          toggleLoop(loop);}


         else { // toggle function here
          mode_state[j][i] = !mode_state[j][i];
          if (mode_state[j][i]) { // hold mode engaged, toggle hold loop
            Switch_Status[j][i+1] = 5;
            loop = hold_array[j][i];
            loops[loop] = 1;
            screenPosition[2] = loop;
            encoderPosition[2] = screenPosition[2] * enc_speed;
            loop = push_array[j][i];
            loops[loop] = 0;
            write_all_loops();


          } else { // hold mode disengaged
            loop = hold_array[j][i];
            loops[loop] = 0;
            loop = push_array[j][i];
            loops[loop] = 0;
            screenPosition[2] = loop;
            encoderPosition[2] = screenPosition[2] * enc_speed;
            Switch_Status[j][i+1] = 0;
            write_all_loops();


          }
          
        }
        screen_time = ct;
      } else if (mux_deb[j][i] >= error_thresh && readMuxButton(i, j) == false && ct > timers[1]) { // check for button push not hold
        timers[1] = ct + 100;
        
        if (mode_state[j][i] == true) { // hold engaged
          loop = hold_array[j][i];
          switch_status_control(j, i + 1, holdtrigger, true);
          screenPosition[2] = loop;
          encoderPosition[2] = screenPosition[2] * enc_speed;
          toggleLoop(loop);
          screen_time = ct;

        } else { // standard function
          loop = push_array[j][i];
          switch_status_control(j, i + 1, holdtrigger, false);
          screenPosition[2] = loop;
          encoderPosition[2] = screenPosition[2] * enc_speed;
          toggleLoop(loop);
          screen_time = ct;

        }
        PrintSerialString1();
      }

      if (readMuxButton(i, j) == false) {
        mux_deb[j][i] = 0;
      }
    }
  }
if(VolumeScreen == false){
  if (screenPosition[1] > label_count) {
    screenPosition[1] = 1;
    encoderPosition[1] = enc_speed;
  }

  if (screenPosition[1] < 1) {
    screenPosition[1] = label_count;
    encoderPosition[1] = enc_speed * label_count;
  }}

  // Read the button state
  
  if (millis() - screen_switch_time >= screen_time && screen_switch_time != 0) {
    encoderPosition[0] = encoderPosition[1];
    screenPosition[0] = screenPosition[1];
  } else {
    encoderPosition[0] = encoderPosition[2];
    screenPosition[0] = screenPosition[2];
 }

  buttonState = digitalRead(buttonPin); // Read button state directly

  // If the button state has changed
  if (buttonState != lastButtonState) {
    if (buttonState == HIGH) { // Button pressed (since it's a pulldown resistor)
      // Toggle loop state
      VolumeScreen = !VolumeScreen;
    }
    lastButtonState = buttonState;
  }

  if (ct + 50 > timers[0]) {
    timers[0] = ct;
    display_color_led_1(Switch_Status[0], leds_1);
    display_color_led_2(Switch_Status[1], leds_2);
    FastLED.show();
    if(VolumeScreen == true){
      updateVolDisplay();}
    else{
      updateDisplay();}
  }
}


//----------------------------------------------------------------------------------------------------------------------------------------------

bool readMuxButton(int button,int muxn) {
  digitalWrite(mux[muxn][0], bitRead(button, 0));
  digitalWrite(mux[muxn][1], bitRead(button, 1));
  digitalWrite(mux[muxn][2], bitRead(button, 2));


  delay(mux[muxn][5]); // Small delay to let the MUX settle
  bool s = !digitalRead(mux[muxn][3]);
  return s;
}

void switch_status_control(int mux, int led,bool trig, bool flip){
  int x = Switch_Status[mux][led];
  if(flip == false){
  if(trig == true){
      switch(x){ // states for hold
    case 0: Switch_Status[mux][led] = 3; break;
    case 1: Switch_Status[mux][led] = 2; break;
    case 2: Switch_Status[mux][led] = 1; break;
    case 3: Switch_Status[mux][led] = 0; break;
  }}
  else{
  switch(x){
    case 0: Switch_Status[mux][led] = 1; break;
    case 1: Switch_Status[mux][led] = 0; break;
    case 2: Switch_Status[mux][led] = 3; break;
    case 3: Switch_Status[mux][led] = 2; break;
  }}
  }
  else{
  if(trig == true){ // states for non-hold
      switch(x){
    case 0: Switch_Status[mux][led] = 5; break;
    case 1: Switch_Status[mux][led] = 4; break;
    case 4: Switch_Status[mux][led] = 1; break;
    case 5: Switch_Status[mux][led] = 0; break;

  }}
  else{
  switch(x){
    case 0: Switch_Status[mux][led] = 1; break;
    case 1: Switch_Status[mux][led] = 0; break;
    case 4: Switch_Status[mux][led] = 5; break;
    case 5: Switch_Status[mux][led] = 4; break;

  }}
}
}



void display_color_led_1(int status_array[], CRGB led_array[]){
for(int i = 1; i < NUM_LEDS; i++){
  int x = status_array[i];
  if(i < 5){
  leds_1[5-i] = CRGB(colors[x][0],colors[x][1],colors[x][2]);}
  else{
    leds_1[13-i] = CRGB(colors[x][0],colors[x][1],colors[x][2]);}
  }
  

}

void display_color_led_2(int status_array[], CRGB led_array[]){
for(int i = 1; i < NUM_LEDS; i++){
  int x = status_array[i];
  if(i < 5){
  leds_2[5-i] = CRGB(colors[x][0],colors[x][1],colors[x][2]);}
  else{
    leds_2[13-i] = CRGB(colors[x][0],colors[x][1],colors[x][2]);}
  }
  

}

void PrintSerialString1(){
  
  Serial.println("Loop status: 1 | 2 | 3 | 4 | 5 | 6 | 7 | 8 ");
    Serial.print("            ");
  Serial.print(Data.loop1);
    Serial.print(" | ");
  Serial.print(Data.loop2);
    Serial.print(" | ");
  Serial.print(Data.loop3);
    Serial.print(" | ");
  Serial.print(Data.loop4);
    Serial.print(" | ");
  Serial.print(Data.loop5);
    Serial.print(" | ");
  Serial.print(Data.loop6);
    Serial.print(" | ");
  Serial.print(Data.loop7);
    Serial.print(" | ");
  Serial.println(Data.loop8);
}

void print_mux(){
for(int x = 0; x < 3; x ++){
  for (int y = 0; y <8;y++){
    Serial.print(mux_deb[x][y]);
    Serial.print(" | ");
  }
}
Serial.println();}

void updateDisplay() {
  display.clearDisplay();
  display.setTextSize(1);
  display.setTextColor(SSD1306_WHITE);
  display.setCursor(0, 10);
  display.print("Selected Loop:");
  
  display.setCursor(100, 10);
  display.print(screenPosition[0]);
  display.setTextSize(2);
  display.setCursor(0, 20);
  if(screenPosition[0] > 12){
      display.print(labels_m3[screenPosition[0]-1-12]);
  }
  else if(screenPosition[0] > 6){
      display.print(labels_m2[screenPosition[0]-1-6]);
  }
  else{
    display.print(labels_m1[screenPosition[0]-1]);
  }
  
  display.setCursor(0, 40);
  display.setTextSize(1);
  display.print("Status:");
  display.setTextSize(2);
  display.setCursor(60, 50);
  display.print(getLoopState(screenPosition[0]) ? "ON" : "OFF");
  display.display();
}

void initLoopState(){
  for(int x = 0; x <6; x++){
    loops[x+1] = loops_m1[x];
    loops[x+7] = loops_m2[x];
    loops[x+13] = loops_m3[x];
  }
    Data.loop1 = loops_m1[0];
    Data.loop2= loops_m1[1];
    Data.loop3= loops_m1[2];
    Data.loop4= loops_m1[3];
    Data.loop5= loops_m1[4];
    Data.loop6= loops_m1[5];
    Data.loop7= loops_m2[0];
    Data.loop8= loops_m2[1];
    Data.loop9= loops_m2[2];
    Data.loop10= loops_m2[3];
    Data.loop11= loops_m2[4];
    Data.loop12= loops_m2[5];
    Data.loop13= loops_m3[0];
    Data.loop14= loops_m3[1];
    Data.loop15= loops_m3[2];
    Data.loop16= loops_m3[3];
    Data.loop17= loops_m3[4];
    Data.loop18= loops_m3[5];


}

bool getLoopState(int loop) {
  switch (loop) {
    case 1: return Data.loop1;
    case 2: return Data.loop2;
    case 3: return Data.loop3;
    case 4: return Data.loop4;
    case 5: return Data.loop5;
    case 6: return Data.loop6;
    case 7: return Data.loop7;
    case 8: return Data.loop8;
    case 9: return Data.loop9;
    case 10: return Data.loop10;
    case 11: return Data.loop11;
    case 12: return Data.loop12;
    case 13: return Data.loop13;
    case 14: return Data.loop14;
    case 15: return Data.loop15;
    case 16: return Data.loop16;
    case 17: return Data.loop17;
    case 18: return Data.loop18;
    case 19: return Data.Vol;
    default: return false;
  }
}

void toggleLoop(int loop) {
  int l = loop;
  loops[l] = !loops[l];
  switch (loop) {
    case 1: Data.loop1 = loops[l]; break;
    case 2: Data.loop2 = loops[l]; break;
    case 3: Data.loop3 = loops[l]; break;
    case 4: Data.loop4 = loops[l]; break;
    case 5: Data.loop5 = loops[l]; break;
    case 6: Data.loop6 = loops[l]; break;
    case 7: Data.loop7 = loops[l]; break;
    case 8: Data.loop8 = loops[l]; break;
    case 9: Data.loop9 = loops[l]; break;
    case 10: Data.loop10 = loops[l]; break;
    case 11: Data.loop11 = loops[l]; break;
    case 12: Data.loop12 = loops[l]; break;
    case 13: Data.loop13 = loops[l]; break;
    case 14: Data.loop14 = loops[l]; break;
    case 15: Data.loop15 = loops[l]; break;
    case 16: Data.loop16 = loops[l]; break;
    case 17: Data.loop17 = loops[l]; break;
    case 18: Data.loop18 = loops[l]; break;
  }
  // Send data over ESP-NOW
  esp_err_t result = esp_now_send(0, (uint8_t *)&Data, sizeof(DataStruct));
}

void write_all_loops(){
  int n = 1;
Data.loop1 = loops[n+0];
Data.loop2 = loops[n+1];
Data.loop3 = loops[n+2];
Data.loop4 = loops[n+3];
Data.loop5 = loops[n+4];
Data.loop6 = loops[n+5];
Data.loop7 = loops[n+6];
Data.loop8 = loops[n+7];
Data.loop9 = loops[n+8];
Data.loop10 = loops[n+9];
Data.loop11 = loops[n+10];
Data.loop12 = loops[n+11];
Data.loop13 = loops[n+12];
Data.loop14 = loops[n+13];
Data.loop15 = loops[n+14];
Data.loop16 = loops[n+15];
Data.loop17 = loops[n+16];
Data.loop18 = loops[n+17];

  esp_err_t result = esp_now_send(0, (uint8_t *)&Data, sizeof(DataStruct));
}

void VolumeHandler(){
  static int lastPosition = 0;
  const int stepsize = 5;
  if(lastPosition < encoderPosition[1] && Vol <= 100-stepsize){
    Vol += 5;
    lastPosition = encoderPosition[1];
    Data.Vol = Vol;
    esp_err_t result = esp_now_send(0, (uint8_t *)&Data, sizeof(DataStruct));
  }
  if(lastPosition > encoderPosition[1] && Vol >= 0+stepsize){
  Vol -= 5;
  lastPosition = encoderPosition[1];
  Data.Vol = Vol;
    esp_err_t result = esp_now_send(0, (uint8_t *)&Data, sizeof(DataStruct));
  }
  else{
    lastPosition = encoderPosition[1];
  }}
  

void updateVolDisplay() {
  display.clearDisplay();
  display.setTextSize(2);
  display.setTextColor(SSD1306_WHITE);
  display.setCursor(0, 10);
  display.print("Volume:");

  display.setTextSize(2);
  display.setCursor(40, 30);
  display.print(Vol);

  display.display();
}

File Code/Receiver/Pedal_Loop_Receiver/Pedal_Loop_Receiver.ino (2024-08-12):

#include <esp_now.h>
#include <WiFi.h>
#define runpin 13

#define pincount 6
const int pins_1[pincount] = {14,27,26,25,33,32};
bool pinstate_1[pincount] = {0,0,0,0,0,0};

const int pins_2[pincount] = {18,19,3,1,23,12};
//const int pins_2[pincount] = {18,19,18,19,23,12};
bool pinstate_2[pincount] = {0,0,0,0,0,0};
// Disable pins 1 and 3 to enable serial coms during runtime
const int pins_3[pincount] = {15,2,4,16,5,17};
bool pinstate_3[pincount] = {0,0,0,0,0,0};

bool printouts = true;

typedef struct DataStruct {
bool loop1;
bool loop2;
bool loop3;
bool loop4;
bool loop5;
bool loop6;
bool loop7;
bool loop8;
bool loop9;
bool loop10;
bool loop11;
bool loop12;
bool loop13;
bool loop14;
bool loop15;
bool loop16;
bool loop17;
bool loop18;
}DataStruct;
DataStruct Data;
#define CHANNEL 1

void setup() {
  Serial.begin(115200);
  Serial.setTimeout(10);
  WiFi.mode(WIFI_STA);
  delay(2000);
  Serial.print("MAC Address: ");
  Serial.println(WiFi.macAddress());
  for(int i = 0; i <pincount; i++){
  pinMode(pins_1[i],OUTPUT);
  Serial.print("Activated Pin: ");
  Serial.print(pins_1[i]);
  Serial.println(" as output");
}
  for(int i = 0; i <pincount; i++){
  pinMode(pins_2[i],OUTPUT);
  Serial.print("Activated Pin: ");
  Serial.print(pins_2[i]);
  Serial.println(" as output");
}
  for(int i = 0; i <pincount; i++){
  pinMode(pins_3[i],OUTPUT);
  Serial.print("Activated Pin: ");
  Serial.print(pins_3[i]);
  Serial.println(" as output");
}

  //Init ESP-NOW
  if (esp_now_init() != ESP_OK) {
    Serial.println("Error initializing ESP-NOW");
    return;}
  esp_now_register_recv_cb(OnDataRecv);

}

void loop() {
if (Serial.available() >= 2 ){
    // Read the integers from Serial
    Data.loop1 = Serial.parseInt();
    Data.loop2 = Serial.parseInt();
    Data.loop3 = Serial.parseInt();
    Data.loop4 = Serial.parseInt();
    Data.loop5 = Serial.parseInt();
    Data.loop6 = Serial.parseInt();
    Data.loop7 = Serial.parseInt();
    Data.loop8 = Serial.parseInt();
    Data.loop9 = Serial.parseInt();
    Data.loop10 = Serial.parseInt();
    Data.loop11 = Serial.parseInt();
    Data.loop12 = Serial.parseInt();
    Data.loop13 = Serial.parseInt();
    Data.loop14 = Serial.parseInt();
    Data.loop15 = Serial.parseInt();
    Data.loop16 = Serial.parseInt();
    Data.loop17 = Serial.parseInt();
    Data.loop18 = Serial.parseInt();

    int BufferClear = Serial.parseInt(); 


    for(int j=0; j<pincount; j++){
  digitalWrite(pins_1[j],pinstate_1[j]);
}

for(int j=0; j<pincount; j++){
  digitalWrite(pins_2[j],pinstate_2[j]);
}

for(int j=0; j<pincount; j++){
  digitalWrite(pins_3[j],pinstate_3[j]);
}
}}

void OnDataRecv(const uint8_t * mac, const uint8_t *incomingData, int len) {
  memcpy(&Data, incomingData, sizeof(Data));
  pinstate_1[0] = Data.loop1;
  pinstate_1[1] = Data.loop2;
  pinstate_1[2] = Data.loop3;
  pinstate_1[3] = Data.loop4;
  pinstate_1[4] = Data.loop5;
  pinstate_1[5] = Data.loop6;

  pinstate_2[0] = Data.loop7;
  pinstate_2[1] = Data.loop8;
  pinstate_2[2] = Data.loop9;
  pinstate_2[3] = Data.loop10;
  pinstate_2[4] = Data.loop11;
  pinstate_2[5] = Data.loop12;

  pinstate_3[0] = Data.loop13;
  pinstate_3[1] = Data.loop14;
  pinstate_3[2] = Data.loop15;
  pinstate_3[3] = Data.loop16;
  pinstate_3[4] = Data.loop17;
  pinstate_3[5] = Data.loop18;



for(int j=0; j<pincount; j++){
  digitalWrite(pins_1[j],pinstate_1[j]);
  if(printouts == true){
  Serial.print("Jack 1 Pin: ");
  Serial.print(pins_1[j]);
  Serial.print("--[");
  Serial.print(pinstate_1[j]);
  Serial.print("]  | ");}
  if(j == pincount-1){Serial.println();}
}

for(int j=0; j<pincount; j++){
  digitalWrite(pins_2[j],pinstate_2[j]);
  if(printouts == true){
  Serial.print("Jack 2 Pin: ");
  Serial.print(pins_2[j]);
  Serial.print("--[");
  Serial.print(pinstate_2[j]);
  Serial.print("]  | ");}
  if(j == pincount-1){Serial.println();}
}

for(int j=0; j<pincount; j++){
  digitalWrite(pins_3[j],pinstate_3[j]);
  if(printouts == true){
  Serial.print("Jack 3 Pin: ");
  Serial.print(pins_3[j]);
  Serial.print("--[");
  Serial.print(pinstate_3[j]);
  Serial.print("]  | ");}
  if(j == pincount-1){Serial.println();}
}



}

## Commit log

2024-06-08 new PCBs
    [8P breakout header-B_Cu.gbr, 8P breakout header-B_Mask.gbr, 8P breakout header-B_Paste.gbr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]
2024-06-10 Pcb load
    [8P breakout header.step, Coms Board V2.step, IO.step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]
2024-07-15 latest Version PCBs
    [Control Board v2.kicad_pcb, Control Board v2.kicad_sch, Expansion Board.kicad_pcb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]
2024-07-15 added 3d models
    [5 Bay Lid.stl, 5 Bay switch.3mf, 5 Bay switch.stl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]
